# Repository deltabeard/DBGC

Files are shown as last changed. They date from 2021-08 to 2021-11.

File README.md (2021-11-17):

# DBGC: Deltabeard's Game Boy Cartridge
A reprogrammable Game Boy cartridge that utilises the Raspberry Pi RP2040.

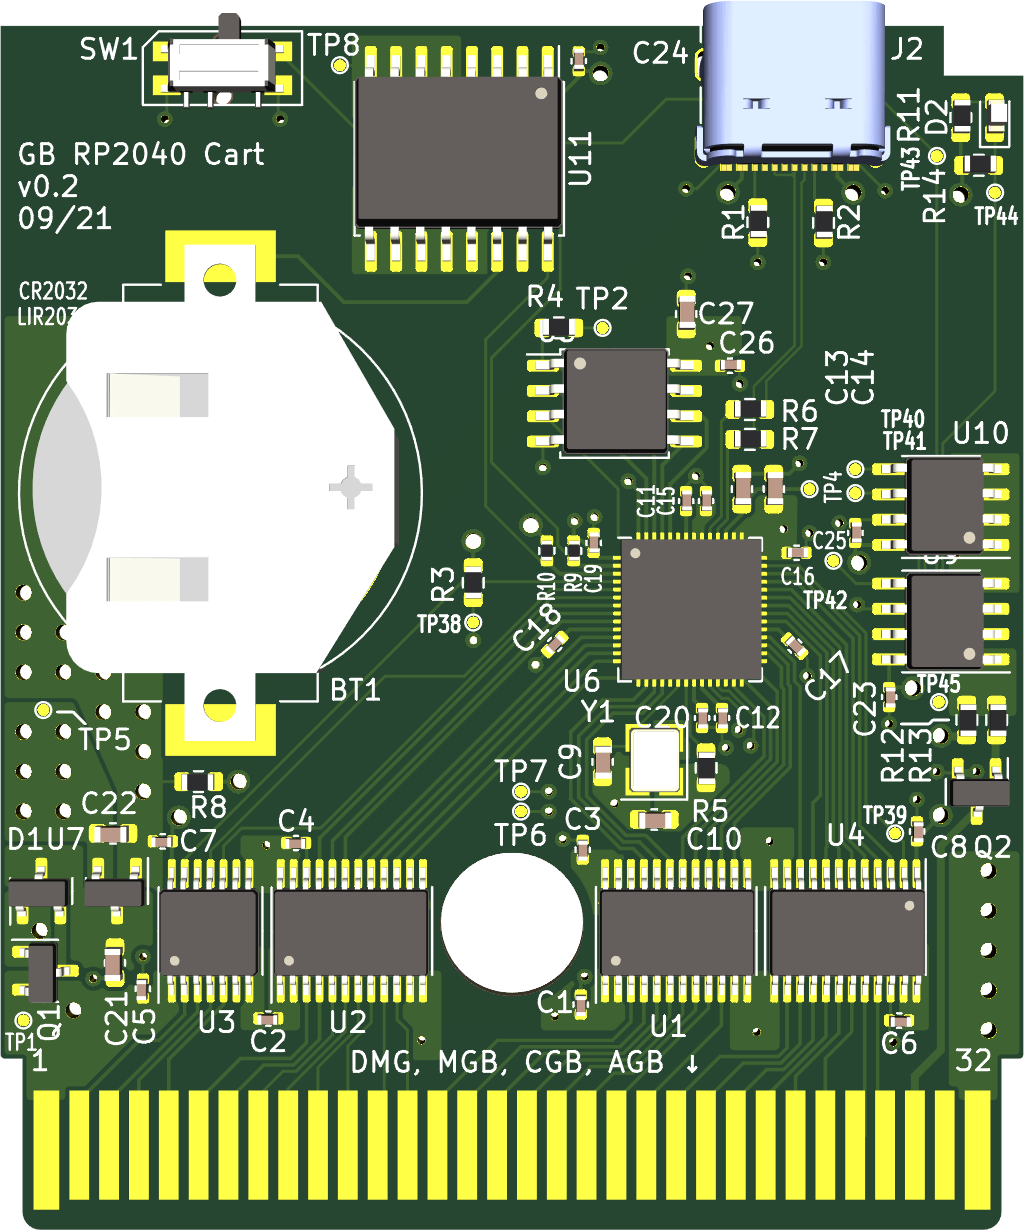
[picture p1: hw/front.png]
Front preview of PCB
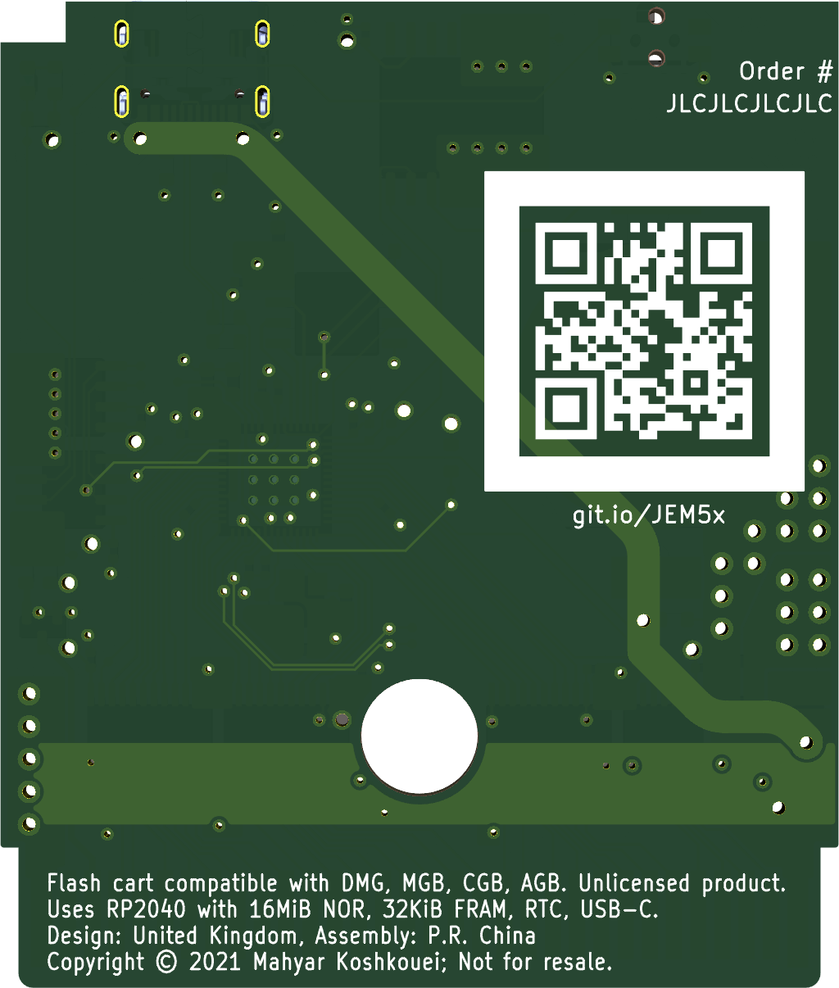
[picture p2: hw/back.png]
Back preview of PCB
 

## Supported Features
- Support for No MBC, MBC1 and MBC3 games (but only in single-speed mode).
- Real Time Clock (RTC) with battery backup.
- FRAM 32KiB for save support.
- NOR Flash 16MiB with support upto 8MiB ROM size.
- Can only play the one game programmed in at compile time.
- USB-C firmware upgrade support.

## Proposed Features

- Support multiple games on NOR Flash.
- USB-C flash storage explorer to store and retrieve save files and ROMs.
- USB-C networking support.

### Flash Storage
The flash storage will be partitioned to allow the user to either support large ROM sizes or increased number of ROMs stored. By setting the maximum ROM size to a smaller value, there will be more space to store other ROMs on the *Storage* partition. An example partition scheme is shown below.

| Partition | Size | Purpose |
|---|  --: |---|
| Firmware | 256KiB | Stores firmware for the RP2040 |
| Storage | Remainder | Wear-levelling filesystem holding ROMs and save files |

### USB-C Networking

By utilising RP2040 and TinyUSB features, the USB-C port can act as a networking device, which when attached to a host, will allow the RP2040 to connect to the Internet. Future features will allow supported Game Boy games to make connections to the internet.

## Notes
BOM is optimised for purchase from JLCPCB with SMT assembly. The cost of producing a single cart of this revision is approximately £15. This version of the PCB has major errors that can be seen in the [errata.md](https://github.com/deltabeard/DBGC/blob/master/errata.md) document. **Do not manufacture PCB version 0.3 or below**; instead wait for the next version or the one on the master branch. 

# License

The majority of the software within this project are licensed under the 
terms of the ISC License. Please see the header of each source file for 
license terms. In brief, the copyright and permission notices must not be
modified.

The PCB schematic and layout are licensed under the 
Creative Commons Attribution-ShareAlike 4.0 International (CC BY-SA 4.0) 
license. In brief, you may modify and share but only under the same license 
to allow others to continue modifying and sharing.

This project includes
[Libbet and the Magic Floor](https://github.com/pinobatch/libbet) and
[2048-gb](https://github.com/Sanqui/2048-gb), which are both 
licensed under the terms of the zlib license, and are included within this
project in an unmodified binary form for testing purposes.

# Showcase

- [Pokemon Polished Crystal](https://github.com/Rangi42/polishedcrystal). A 
  major fan-made upgrade to Pokemon Crystal. Uses MBC3 with battery backed 
  SRAM and Real Time Clock. The version tested had CGB double-speed disabled,
  which caused minor graphical glitches within the game. An effort is made to
  fix these graphical glitches at https://github.com/deltabeard/polishedcrystal.
  DBGC does not currently support double-speed, so using it to play
  Polished Crystal may not result in the intended experience.

Pokemon Polished Crystal

- Mega Man 1. This commercial game uses MBC1 ROM banking.

megaman1

- [2048-gb](https://github.com/Sanqui/2048-gb). Open source homebrew game. 
  Uses no ROM banking.



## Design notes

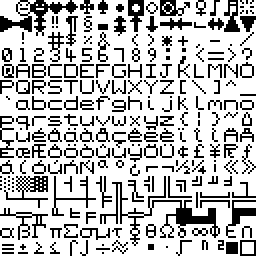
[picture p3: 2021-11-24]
sw/dmg/F77SMC6.png

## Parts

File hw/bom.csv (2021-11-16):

Comment | Designator | Footprint | LCSC
Battery_Cell | BT1 | Project_Specific:MY-2032-11 | C964835
100n | C1,C2,C3,C4,C5,C6,C7,C8,C10,C13,C14,C16,C17,C18,C19,C20,C21,C26,C27 | Capacitor_SMD:C_0402_1005Metric | C1525
30p | C11,C12 | Capacitor_SMD:C_0402_1005Metric | C1570
1u | C9,C15,C22,C23,C24 | Capacitor_SMD:C_0402_1005Metric | C52923
D_Dual_CommonCathode_AAK_Split | D1 | Package_TO_SOT_SMD:SOT-23 | C68978
LED | D2 | LED_SMD:LED_0603_1608Metric | C2286
SM4007PL | D3 | Diode_SMD:D_SOD-123F | C64898
GameBoy_Cartridge | J1 | Gekkio_Connector_PCBEdge:GameBoy_Cartridge_1x32_P1.50mm_Full
USB_C_Receptacle_USB2.0 | J2 | Connector_USB:USB_C_Receptacle_Palconn_UTC16-G | C167321
Debug | J3 | Connector_PinSocket_1.27mm:PinSocket_1x03_P1.27mm_Vertical
Motor_DC | M1 | Connector_PinHeader_1.27mm:PinHeader_1x02_P1.27mm_Vertical
SI2301CDS-T1-GE3 | Q1 | Package_TO_SOT_SMD:SOT-23 | C10487
N-Channel | Q2,Q3 | Package_TO_SOT_SMD:SOT-23 | C8545
25k | R1,R2,R3,R12 | Resistor_SMD:R_0402_1005Metric | C25900
100k | R10 | Resistor_SMD:R_0603_1608Metric | C25803
330R | R11,R13,R14 | Resistor_SMD:R_0603_1608Metric | C23138
5k1 | R4,R5 | Resistor_SMD:R_0402_1005Metric | C25905
1k | R6,R7 | Resistor_SMD:R_0603_1608Metric | C21190
27.4R | R8,R9 | Resistor_SMD:R_0603_1608Metric | C25190
SW_SPST | SW1 | Button_Switch_SMD:SW_SPST_TL3342 | C318886
TestPoint | TP1,TP2 | TestPoint:TestPoint_Pad_D1.0mm
TestPoint | TP3,TP5 | TestPoint:TestPoint_THTPad_D1.0mm_Drill0.5mm
SN74LVC8T245PW | U1,U2,U4 | Package_SO:TSSOP-24_4.4x7.8mm_P0.65mm | C27643
TXU0104 | U3 | Package_SO:TSSOP-14_4.4x5mm_P0.65mm
W25Q128JVSIQ | U5 | Package_SO:SOIC-8_5.23x5.23mm_P1.27mm | C97521
RP2040 | U6 | RP_RP2040:RP2040-QFN-56 | C2040
XC6206P332MR | U7 | Package_TO_SOT_SMD:SOT-23 | C5446
DS1302Z+ | U8 | Package_SO:SOIC-8_3.9x4.9mm_P1.27mm | C265479
MB85RS256B | U9 | Package_SO:SOIC-8_3.9x4.9mm_P1.27mm | C8742
Crystal_GND24 | Y1 | Crystal:Crystal_SMD_3225-4Pin_3.2x2.5mm | C9002
32.768kHz | Y2 | Crystal:Crystal_SMD_Abracon_ABS25-4Pin_8.0x3.8mm | C252402

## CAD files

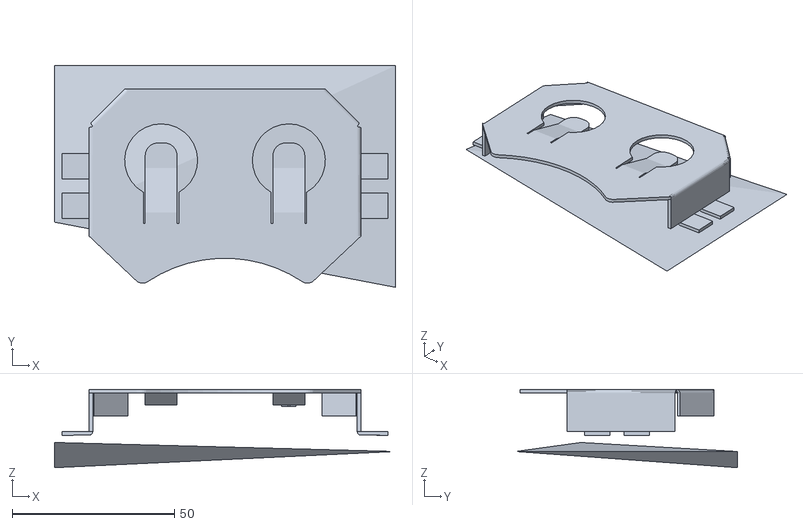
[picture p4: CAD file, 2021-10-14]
hw/models/OBJ_NEW_PCB.obj
105.1 x 68.3 x 24.2

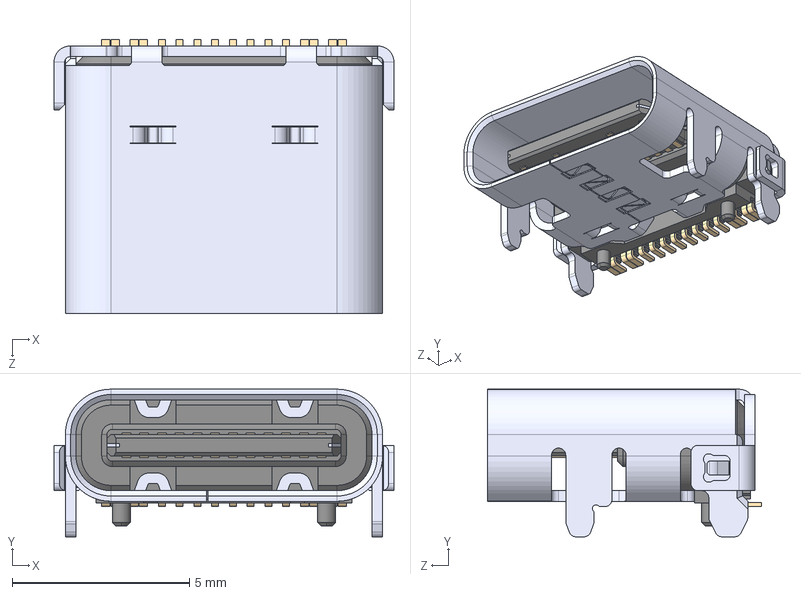
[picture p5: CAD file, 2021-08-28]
hw/models/USB4105-GF-A.step
9.58 x 4.16 x 7.71 mm

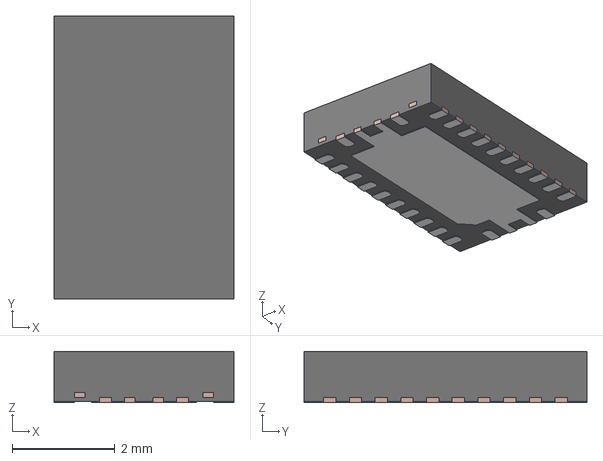
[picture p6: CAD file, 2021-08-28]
hw/models/CLXC8T245QRHLRQ1.stp
3.50 x 5.50 x 1.00 mm
FRAME
MOLD

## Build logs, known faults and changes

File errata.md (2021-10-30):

# Errata

Problems that cannot be solved via software updates.

## PCB dated "09/21"

### Major
- USB differential signals are connected the wrong way round.
  The fix is to cross the signals at the resistors using magnet wire (or alternative).
- The IO2 and IO3 connections to the NOR Flash are connected incorrectly. Possible fixes:
  - Use magnet wire to cross the IO2 and IO3 signals. v0.2 and above requires this fix.
  - Use single-IO or dual-IO flash access, which use IO0 or IO0 and IO1, respectively.
  
### Minor
- The CR2032 cell holder is too far in the PCB, making it difficult to remove the cell from the holder.
- The RTC IC is too close to the top edge of the PCB, making it difficult to place within a GB cartridge enclosure.
- The LED light does not work.

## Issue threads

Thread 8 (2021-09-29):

hw: the LED light does not work

deltabeard, 2021-09-29:

deltabeard, 2021-11-17:
Won't fix. The PCB fab did not populate the LED in the correct orientation.

Closed 2021-11-17.

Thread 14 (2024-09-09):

Add RP2350 support

deltabeard, 2024-09-09:
The RP2350 has improvements to the PIO that includes:

- Improved GPIO input/output delay and skew
- Reduced DMA request (DREQ) latency by one cycle vs RP2040
- Use of PSRAM

These features may allow for improvements in DBGC, and possibly allow for support for CGB clock speed games.

8bitZeta, 2024-12-03:
Are there any updates to this?

deltabeard, 2024-12-04:
No. I don't think changes of the RP2350 are enough to support double speed. With the larger internal RAM, it may be possible to play games at double speed, but the communication with the PSRAM and NOR Flash are still limited to their maximum frequency  of 133 MHz. So larger games that need to run off of external storage will be too slow for CGB double speed games.

Only other method is to use a parallel flash/RAM module and use the RP2040 or RP2530 as a MBC chip.

8bitZeta, 2024-12-07:
How feasible do you think the parallel approach would be?

I know the current metric is using an FPGA/CPLD to stand-in for the MBC, but I feel if it could be completely replicated via simple RPi chips, that would far easier to create and maintain.

deltabeard, 2024-12-14:
The issue is the time taken to obtain the date requested on the parallel bus by the Game Boy from the SPI NOR flash by the RP2040. The NOR Flash is typically limited to 133MHz, but maybe Hyperram, or something similar, could be used instead to obtain the ROM data with sufficient speed. This is because Hyperram is 200MHz and also uses double data rate (DDR). The RP2040 or RP2350 would have to use the PIO to communicate with the Hyperram, as the RP2040 and RP2350 does not support DDR in their QSPI peripheral. It may be possible to determine how much time it would take to receive a byte of data from the Hyperram using the PIO.

My suggestion earlier was to have a parallel flash chip connected directly to the parallel bus, which would remove the delay in the RP2040 getting the data from the SPI flash. But I haven't explored how that would exactly work. The MBC would be emulated by the RP2040, as processing data on the internal SRAM is very fast.

To that end, ROMs that are small enough to be stored entirely within the RP2040 SRAM should be able to run at double speed, but CGB games are typically much larger than the size of the RP2040 SRAM. Although, some CGB games use at least 512kB flash, they only use a small number of bank in their code.

deltabeard, 2024-12-14:
Since the DMG is ~4.2MHz, the cart has ~238nS to put the ROM data onto the bus. In double speed mode at ~8.4MHz, the cart has ~119nS to put the ROM data onto the bus.

A QSPI NOR Flash at 133MHz that can use Fast Read Quad I/O (EBh), would take 21 clock cycles to read the first byte of data from the flash given an address. This would take at least `(1/133e6)*21*1e9=` 158nS, which is okay for DMG but too slow for CGB double speed. This of course doesn't take into account the delay in the RP2040 reading the address from the cart bus, processing it for MBC commands, and any delays on the internal RP2040 CPU bus.

With the Hyperram, or an alternative Octa-SPI DDR chip, the time taken for the Hyperram to return the first byte of data when given a read instruction and the address is `(cmd_addr_clocks+cmd_full_latency)*data_rate*1e9=` 50nS, where `cmd_addr_clocks` is the number of clock transitions required for the command (6); `cmd_full_latency` is the number of clock transitions until the first data is issued by the Hyperram when the longest duration of latency is considered (14); and data_rate is half a period, since the Hyperram is DDR.
Since the Hyperram requires only at least 50nS, that leaves a good ~70nS to take into account other delays. An additional delay is the PIO peripheral.

It might be possible to support the CGB double speed mode with the RP2040 and RP2350. Although I do not think that the RP2350 introduces any much benefit over the RP2040 in this use case.

To save even more time, since the Hyperram is 8-bit bus, maybe the pins of the Hyperram could be connected to the Game Boy bus directly using a switch. So instead of the RP2040 reading this data and then putting it on the Game Boy bus, the Hyperram bus could be connected to the Game Boy bus directly, with a switch controlling when the Hyperram should be driving the bus.

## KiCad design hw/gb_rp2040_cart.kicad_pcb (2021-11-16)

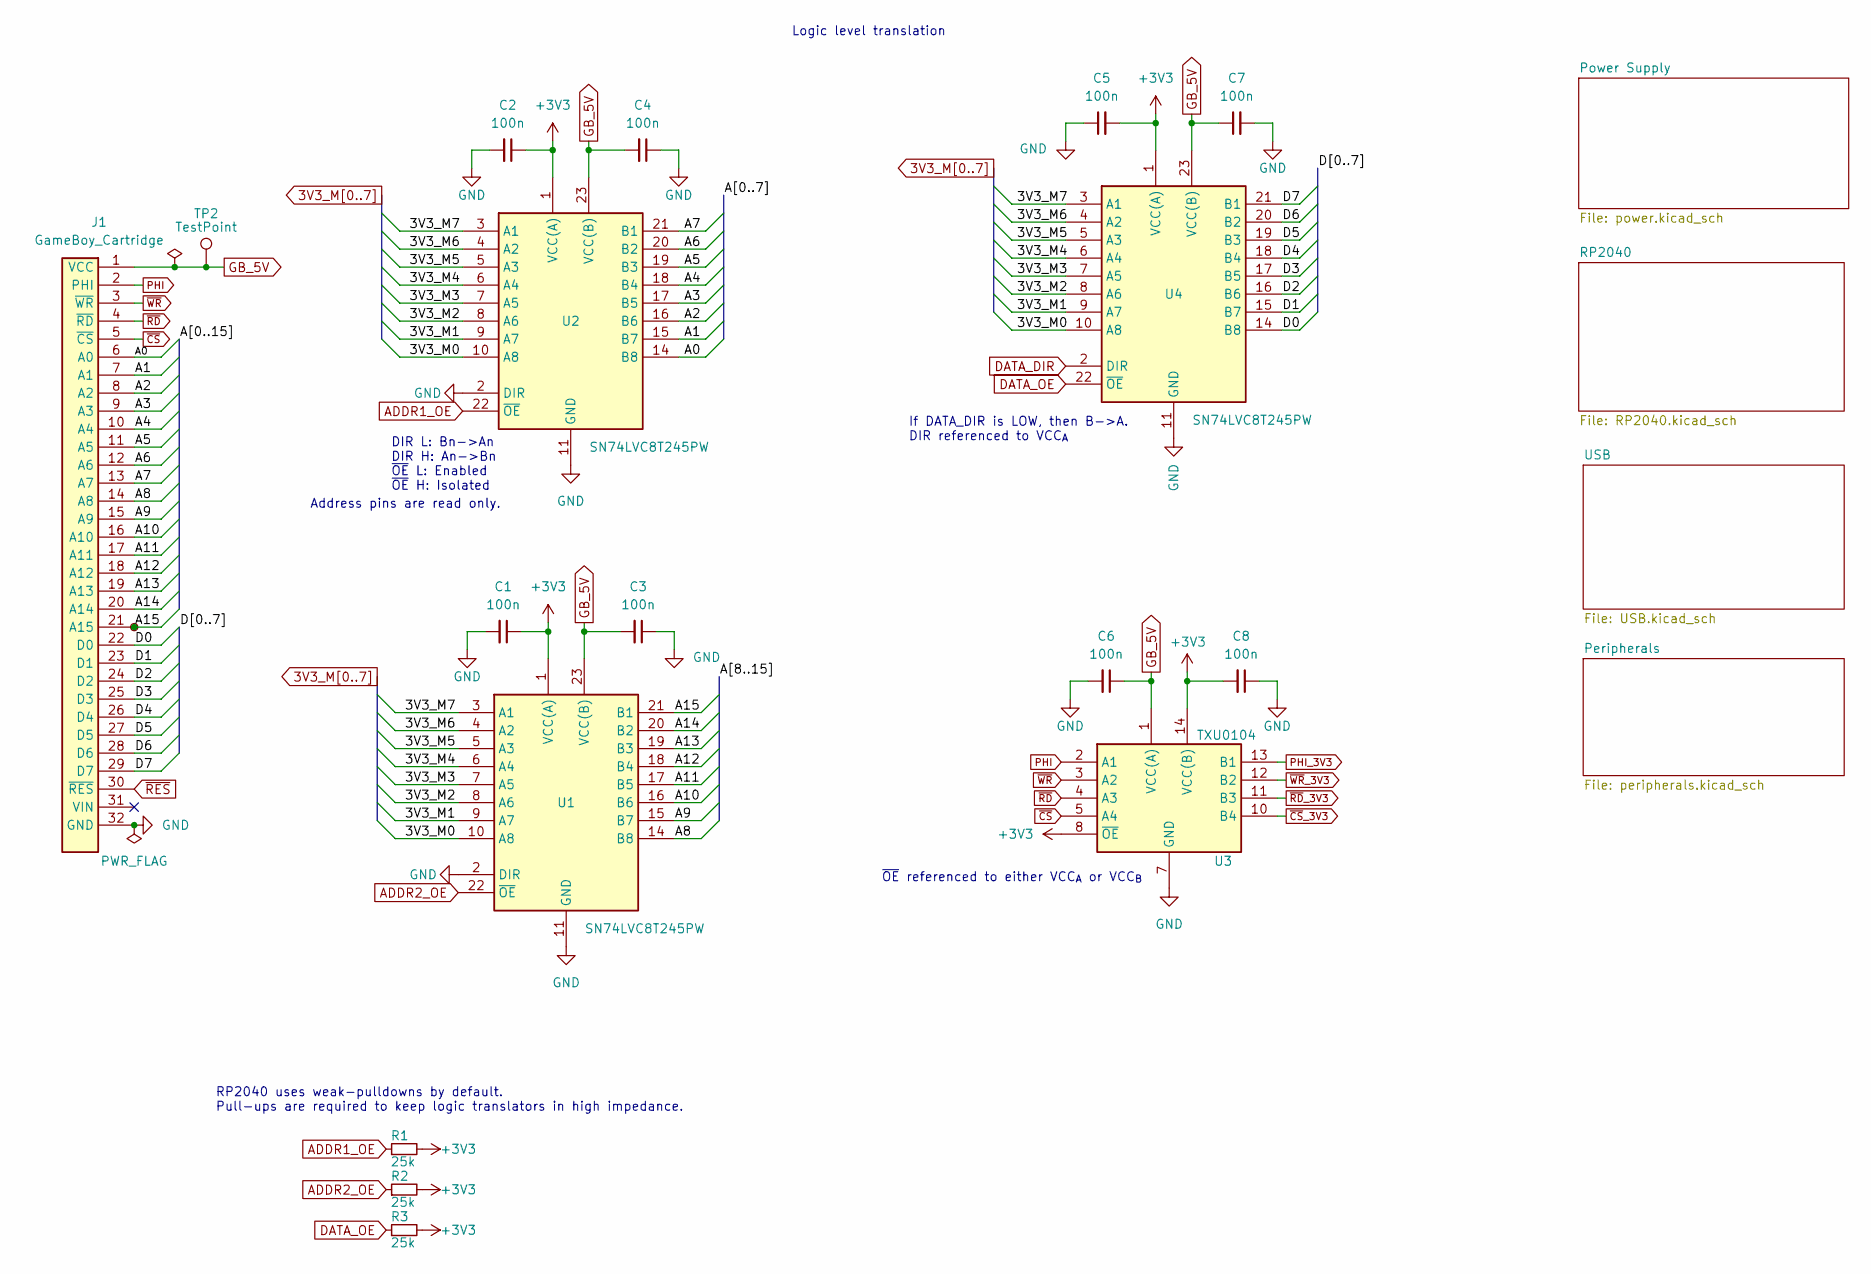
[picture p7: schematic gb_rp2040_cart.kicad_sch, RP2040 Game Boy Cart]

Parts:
C1, C2, C3, C4, C5, C6, C7, C8: 100n; C_0402_1005Metric; LCSC C1525
J1: GameBoy_Cartridge; GameBoy_Cartridge_1x32_P1.50mm_Full
R1, R2, R3: 25k; R_0402_1005Metric; LCSC C25900
TP1, TP2: TestPoint; TestPoint_Pad_D1.0mm
U1, U2, U4: SN74LVC8T245PW; TSSOP-24_4.4x7.8mm_P0.65mm; LCSC C27643
U3: TXU0104; TSSOP-14_4.4x5mm_P0.65mm

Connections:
3V3_M0: U1.10 (A8), U2.10 (A8), U4.10 (A8); also elsewhere on the board
3V3_M1: U1.9 (A7), U2.9 (A7), U4.9 (A7); also elsewhere on the board
3V3_M2: U1.8 (A6), U2.8 (A6), U4.8 (A6); also elsewhere on the board
3V3_M3: U1.7 (A5), U2.7 (A5), U4.7 (A5); also elsewhere on the board
3V3_M4: U1.6 (A4), U2.6 (A4), U4.6 (A4); also elsewhere on the board
3V3_M5: U1.5 (A3), U2.5 (A3), U4.5 (A3); also elsewhere on the board
3V3_M6: U1.4 (A2), U2.4 (A2), U4.4 (A2); also elsewhere on the board
3V3_M7: U1.3 (A1), U2.3 (A1), U4.3 (A1); also elsewhere on the board
+3V3: C1.1, C2.1, C5.2, C8.2, R1.2, R2.2, R3.2, U1.1 (VCC(A)), U2.1 (VCC(A)), U3.8 (~OE), U3.14 (VCC(B)), U4.1 (VCC(A)); also elsewhere on the board
/A0: J1.6 (A0), U2.14 (B8)
/A1: J1.7 (A1), U2.15 (B7)
/A2: J1.8 (A2), U2.16 (B6)
/A3: J1.9 (A3), U2.17 (B5)
/A4: J1.10 (A4), U2.18 (B4)
/A5: J1.11 (A5), U2.19 (B3)
/A6: J1.12 (A6), U2.20 (B2)
/A7: J1.13 (A7), U2.21 (B1)
/A8: J1.14 (A8), U1.14 (B8)
/A9: J1.15 (A9), U1.15 (B7)
/A10: J1.16 (A10), U1.16 (B6)
/A11: J1.17 (A11), U1.17 (B5)
/A12: J1.18 (A12), U1.18 (B4)
/A13: J1.19 (A13), U1.19 (B3)
/A14: J1.20 (A14), U1.20 (B2)
/A15: J1.21 (A15), TP1.1, U1.21 (B1)
/D0: J1.22 (D0), U4.14 (B8)
/D1: J1.23 (D1), U4.15 (B7)
/D2: J1.24 (D2), U4.16 (B6)
/D3: J1.25 (D3), U4.17 (B5)
/D4: J1.26 (D4), U4.18 (B4)
/D5: J1.27 (D5), U4.19 (B3)
/D6: J1.28 (D6), U4.20 (B2)
/D7: J1.29 (D7), U4.21 (B1)
ADDR1_OE: R1.1, U2.22 (~OE); also elsewhere on the board
ADDR2_OE: R2.1, U1.22 (~OE); also elsewhere on the board
DATA_DIR: U4.2 (DIR); also elsewhere on the board
DATA_OE: R3.1, U4.22 (~OE); also elsewhere on the board
GB_5V: C3.2, C4.2, C6.1, C7.1, J1.1 (VCC), TP2.1, U1.23 (VCC(B)), U1.24 (VCC(B)), U2.23 (VCC(B)), U2.24 (VCC(B)), U3.1 (VCC(A)), U4.23 (VCC(B)), U4.24 (VCC(B)); also elsewhere on the board
PHI: J1.2 (PHI), U3.2 (A1)
PHI_3V3: U3.13 (B1); also elsewhere on the board
~CS: J1.5 (~CS), U3.5 (A4)
~CS_3V3: U3.10 (B4); also elsewhere on the board
~RD: J1.4 (~RD), U3.4 (A3)
~RD_3V3: U3.11 (B3); also elsewhere on the board
~RES: J1.30 (~RES); also elsewhere on the board
~WR: J1.3 (~WR), U3.3 (A2)
~WR_3V3: U3.12 (B2); also elsewhere on the board

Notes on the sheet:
RP2040 uses weak-pulldowns by default. Pull-ups are required to keep logic translators in high impedance.
Address pins are read only.
DIR L: Bn->An DIR H: An->Bn ~{OE} L: Enabled ~{OE} H: Isolated
Logic level translation
~{OE} referenced to either VCC_{A} or VCC_{B}
If DATA_DIR is LOW, then B->A. DIR referenced to VCC_{A}

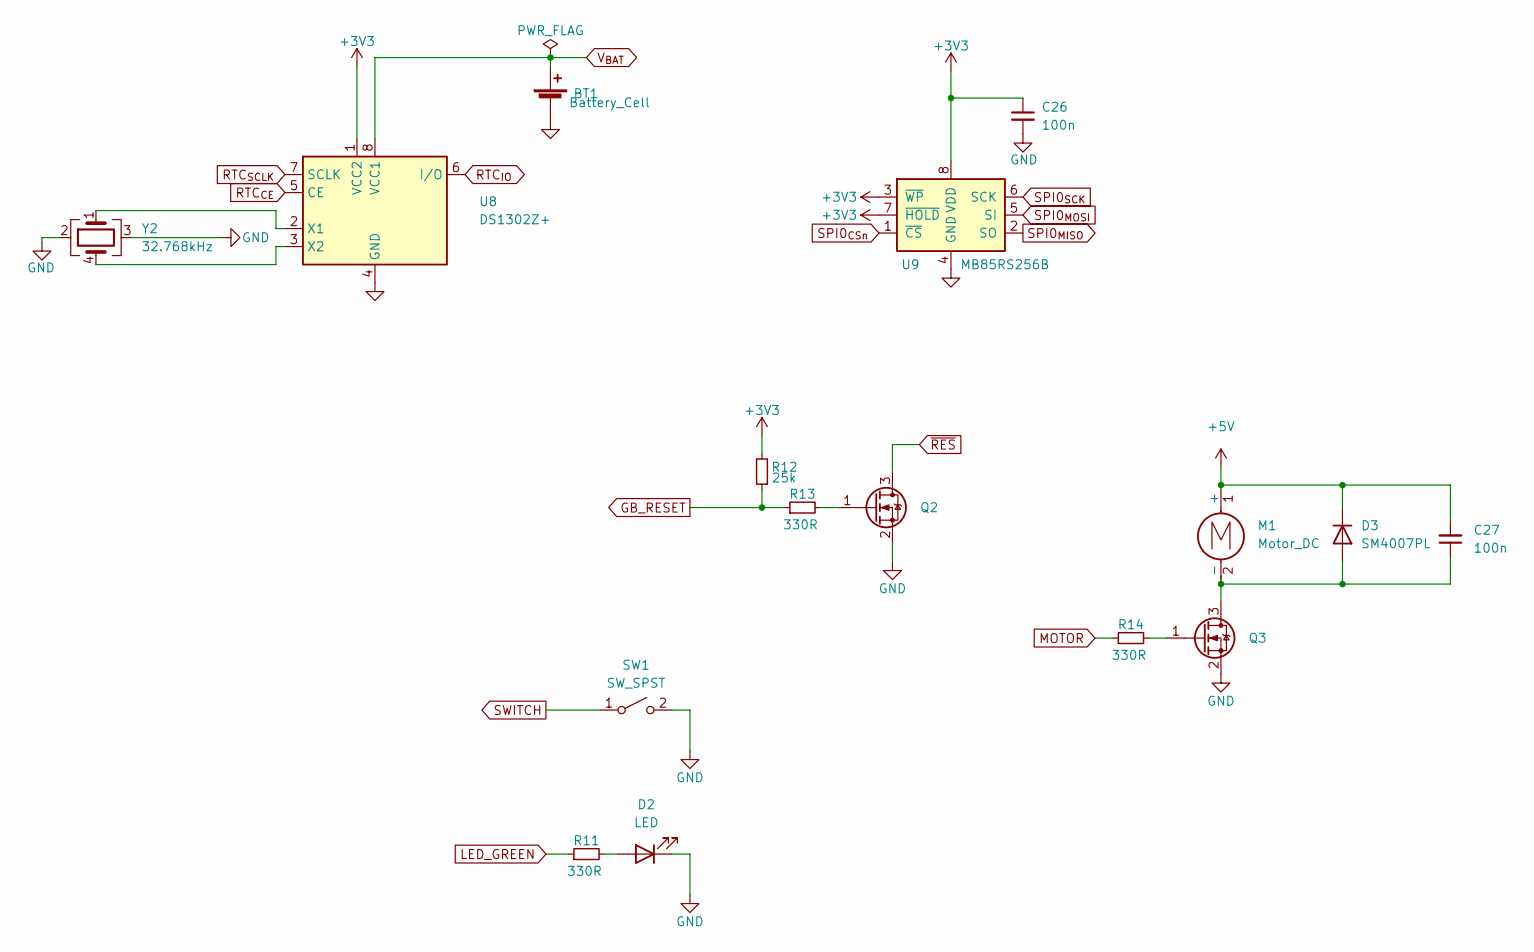
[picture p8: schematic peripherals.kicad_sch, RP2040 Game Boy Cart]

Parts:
BT1: Battery_Cell; MY-2032-11; LCSC C964835
C26, C27: 100n; C_0402_1005Metric; LCSC C1525
D2: LED; LED_0603_1608Metric; LCSC C2286
D3: SM4007PL; D_SOD-123F; LCSC C64898
M1: Motor_DC; PinHeader_1x02_P1.27mm_Vertical
Q2, Q3: N-Channel; SOT-23; LCSC C8545
R11, R13, R14: 330R; R_0603_1608Metric; LCSC C23138
R12: 25k; R_0402_1005Metric; LCSC C25900
SW1: SW_SPST; SW_SPST_TL3342; LCSC C318886
U8: DS1302Z+; SOIC-8_3.9x4.9mm_P1.27mm; LCSC C265479
U9: MB85RS256B; SOIC-8_3.9x4.9mm_P1.27mm; LCSC C8742
Y2: 32.768kHz; Crystal_SMD_Abracon_ABS25-4Pin_8.0x3.8mm; LCSC C252402

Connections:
+3V3: C26.1, R12.2, U8.1 (VCC2), U9.3 (~WP), U9.7 (~HOLD), U9.8 (VDD); also elsewhere on the board
+5V: C27.2, D3.1 (K), M1.1 (+); also elsewhere on the board
GB_RESET: R12.1, R13.1; also elsewhere on the board
LED_GREEN: R11.1; also elsewhere on the board
MOTOR: R14.1; also elsewhere on the board
unnamed: C27.1, D3.2 (A), M1.2 (-), Q3.3 (D)
unnamed: D2.2 (A), R11.2
unnamed: Q2.1 (G), R13.2
unnamed: Q3.1 (G), R14.2
unnamed: U8.2 (X1), Y2.1
unnamed: U8.3 (X2), Y2.4
RTC_{CE}: U8.5 (CE); also elsewhere on the board
RTC_{IO}: U8.6 (I/O); also elsewhere on the board
RTC_{SCLK}: U8.7 (SCLK); also elsewhere on the board
SPI0_{CSn}: U9.1 (~CS); also elsewhere on the board
SPI0_{MISO}: U9.2 (SO); also elsewhere on the board
SPI0_{MOSI}: U9.5 (SI); also elsewhere on the board
SPI0_{SCK}: U9.6 (SCK); also elsewhere on the board
SWITCH: SW1.1 (A); also elsewhere on the board
V_{BAT}: BT1.1 (+), U8.8 (VCC1)
~RES: Q2.3 (D); also elsewhere on the board

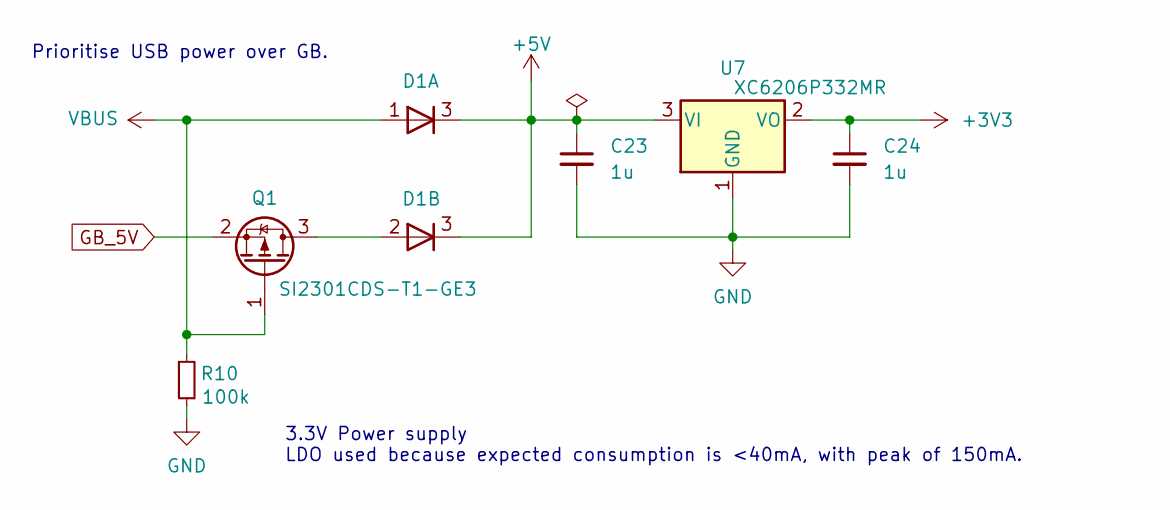
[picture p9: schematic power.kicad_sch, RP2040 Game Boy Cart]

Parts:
C23, C24: 1u; C_0402_1005Metric; LCSC C52923
D1: D_Dual_CommonCathode_AAK_Split; SOT-23; LCSC C68978
Q1: SI2301CDS-T1-GE3; SOT-23; LCSC C10487
R10: 100k; R_0603_1608Metric; LCSC C25803
U7: XC6206P332MR; SOT-23; LCSC C5446

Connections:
+3V3: C24.1, U7.2 (VO); also elsewhere on the board
+5V: C23.1, D1.3 (K), U7.3 (VI); also elsewhere on the board
GB_5V: Q1.2 (S); also elsewhere on the board
unnamed: D1.2 (K), Q1.3 (D)
VBUS: D1.1 (A), Q1.1 (G), R10.1; also elsewhere on the board

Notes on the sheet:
Prioritise USB power over GB.
3.3V Power supply LDO used because expected consumption is <40mA, with peak of 150mA.

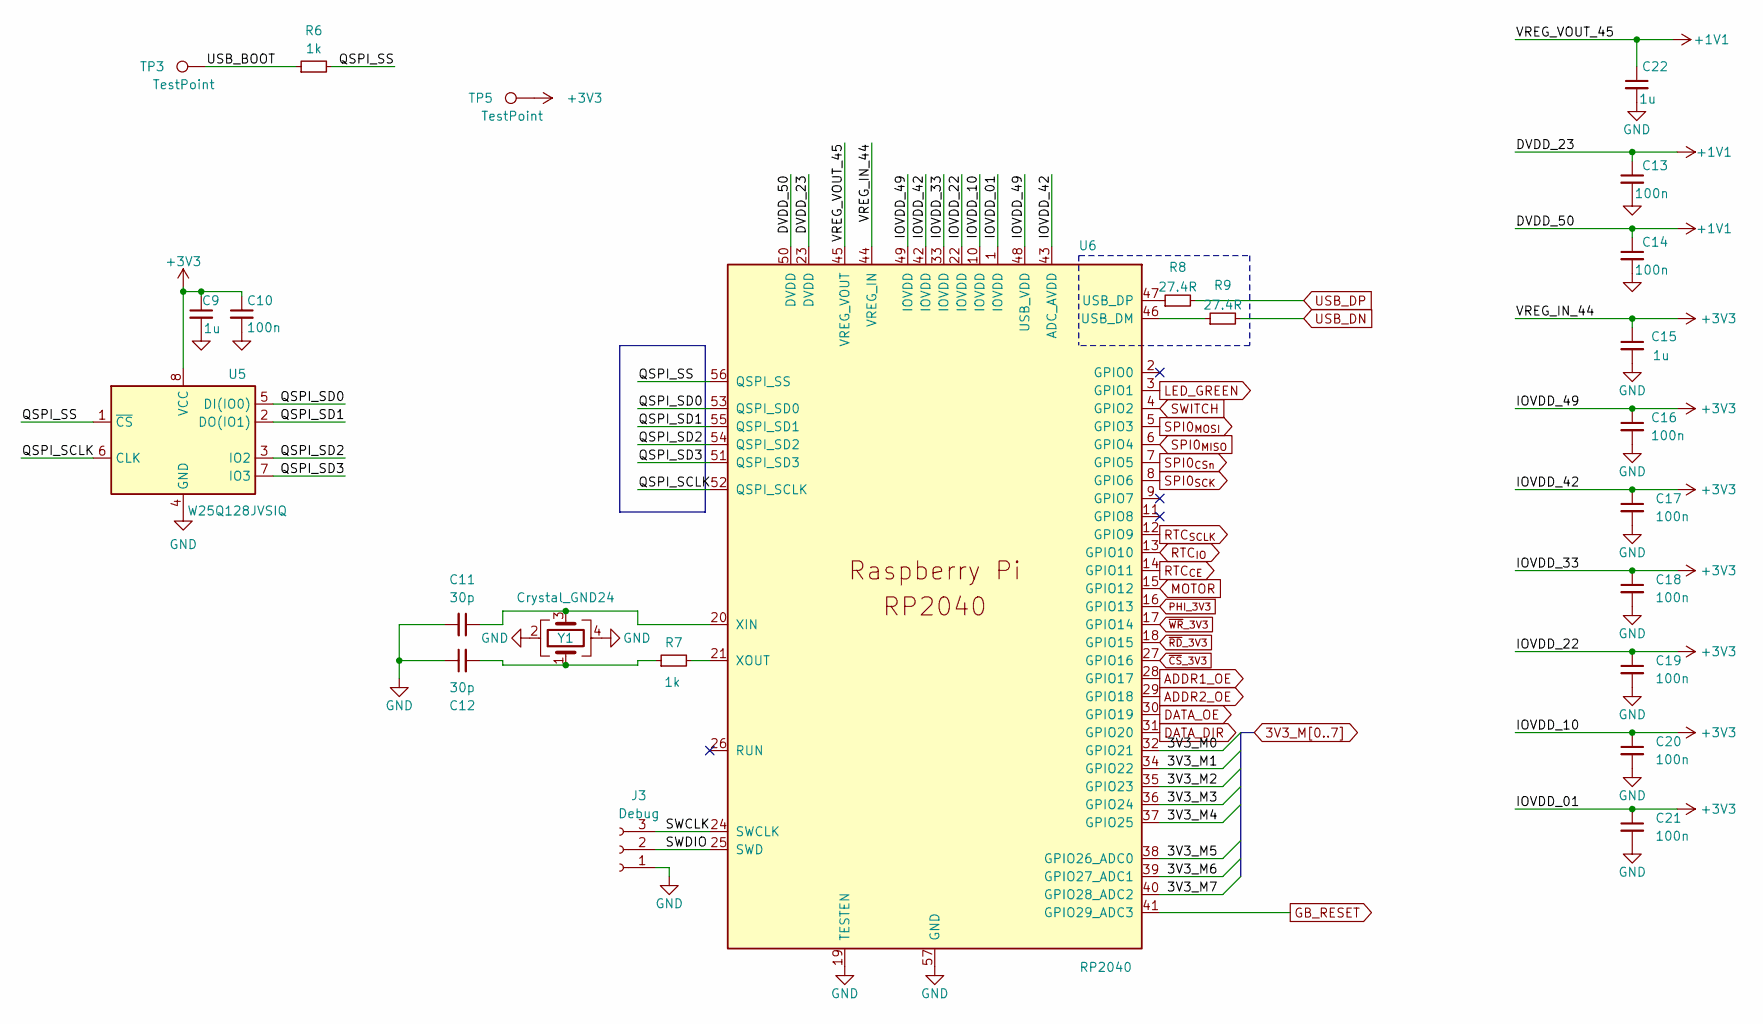
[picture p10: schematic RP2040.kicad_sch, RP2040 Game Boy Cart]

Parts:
C9, C15, C22: 1u; C_0402_1005Metric; LCSC C52923
C10, C13, C14, C16, C17, C18, C19, C20, C21: 100n; C_0402_1005Metric; LCSC C1525
C11, C12: 30p; C_0402_1005Metric; LCSC C1570
J3: Debug; PinSocket_1x03_P1.27mm_Vertical
R6, R7: 1k; R_0603_1608Metric; LCSC C21190
R8, R9: 27.4R; R_0603_1608Metric; LCSC C25190
TP3, TP5: TestPoint; TestPoint_THTPad_D1.0mm_Drill0.5mm
U5: W25Q128JVSIQ; SOIC-8_5.23x5.23mm_P1.27mm; LCSC C97521
U6: RP2040; RP2040-QFN-56; LCSC C2040
Y1: Crystal_GND24; Crystal_SMD_3225-4Pin_3.2x2.5mm; LCSC C9002

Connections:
3V3_M0: U6.32 (GPIO21); also elsewhere on the board
3V3_M1: U6.34 (GPIO22); also elsewhere on the board
3V3_M2: U6.35 (GPIO23); also elsewhere on the board
3V3_M3: U6.36 (GPIO24); also elsewhere on the board
3V3_M4: U6.37 (GPIO25); also elsewhere on the board
3V3_M5: U6.38 (GPIO26_ADC0); also elsewhere on the board
3V3_M6: U6.39 (GPIO27_ADC1); also elsewhere on the board
3V3_M7: U6.40 (GPIO28_ADC2); also elsewhere on the board
+1V1: C13.1, C14.1, C22.1, U6.23 (DVDD), U6.45 (VREG_VOUT), U6.50 (DVDD)
+3V3: C9.1, C10.1, C15.1, C16.1, C17.1, C18.1, C19.1, C20.1, C21.1, TP5.1, U5.8 (VCC), U6.1 (IOVDD), U6.10 (IOVDD), U6.22 (IOVDD), U6.33 (IOVDD), U6.42 (IOVDD), U6.43 (ADC_AVDD), U6.44 (VREG_IN), U6.48 (USB_VDD), U6.49 (IOVDD); also elsewhere on the board
/RP2040/QSPI_SCLK: U5.6 (CLK), U6.52 (QSPI_SCLK)
/RP2040/QSPI_SD0: U5.5 (DI(IO0)), U6.53 (QSPI_SD0)
/RP2040/QSPI_SD1: U5.2 (DO(IO1)), U6.55 (QSPI_SD1)
/RP2040/QSPI_SD2: U5.3 (IO2), U6.54 (QSPI_SD2)
/RP2040/QSPI_SD3: U5.7 (IO3), U6.51 (QSPI_SD3)
/RP2040/QSPI_SS: R6.2, U5.1 (~CS), U6.56 (QSPI_SS)
/RP2040/SWCLK: J3.3, U6.24 (SWCLK)
/RP2040/SWDIO: J3.2, U6.25 (SWD)
/RP2040/USB_BOOT: R6.1, TP3.1
ADDR1_OE: U6.28 (GPIO17); also elsewhere on the board
ADDR2_OE: U6.29 (GPIO18); also elsewhere on the board
DATA_DIR: U6.31 (GPIO20); also elsewhere on the board
DATA_OE: U6.30 (GPIO19); also elsewhere on the board
GB_RESET: U6.41 (GPIO29_ADC3); also elsewhere on the board
LED_GREEN: U6.3 (GPIO1); also elsewhere on the board
MOTOR: U6.15 (GPIO12); also elsewhere on the board
unnamed: C11.1, U6.20 (XIN), Y1.3
unnamed: C12.2, R7.1, Y1.1
unnamed: R7.2, U6.21 (XOUT)
unnamed: R8.1, U6.47 (USB_DP)
unnamed: R9.1, U6.46 (USB_DM)
PHI_3V3: U6.16 (GPIO13); also elsewhere on the board
RTC_{CE}: U6.14 (GPIO11); also elsewhere on the board
RTC_{IO}: U6.13 (GPIO10); also elsewhere on the board
RTC_{SCLK}: U6.12 (GPIO9); also elsewhere on the board
SPI0_{CSn}: U6.7 (GPIO5); also elsewhere on the board
SPI0_{MISO}: U6.6 (GPIO4); also elsewhere on the board
SPI0_{MOSI}: U6.5 (GPIO3); also elsewhere on the board
SPI0_{SCK}: U6.8 (GPIO6); also elsewhere on the board
SWITCH: U6.4 (GPIO2); also elsewhere on the board
USB_DN: R9.2; also elsewhere on the board
USB_DP: R8.2; also elsewhere on the board
~CS_3V3: U6.27 (GPIO16); also elsewhere on the board
~RD_3V3: U6.18 (GPIO15); also elsewhere on the board
~WR_3V3: U6.17 (GPIO14); also elsewhere on the board

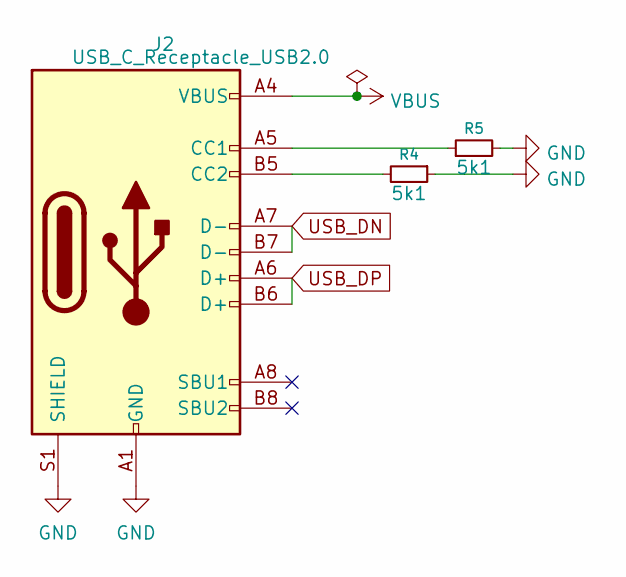
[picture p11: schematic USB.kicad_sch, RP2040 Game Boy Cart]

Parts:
J2: USB_C_Receptacle_USB2.0; USB_C_Receptacle_Palconn_UTC16-G; LCSC C167321
R4, R5: 5k1; R_0402_1005Metric; LCSC C25905

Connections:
unnamed: J2.A5 (CC1), R5.1
unnamed: J2.B5 (CC2), R4.2
USB_DN: J2.A7 (D-), J2.B7 (D-); also elsewhere on the board
USB_DP: J2.A6 (D+), J2.B6 (D+); also elsewhere on the board
VBUS: J2.A4 (VBUS), J2.A9 (VBUS), J2.B4 (VBUS), J2.B9 (VBUS); also elsewhere on the board

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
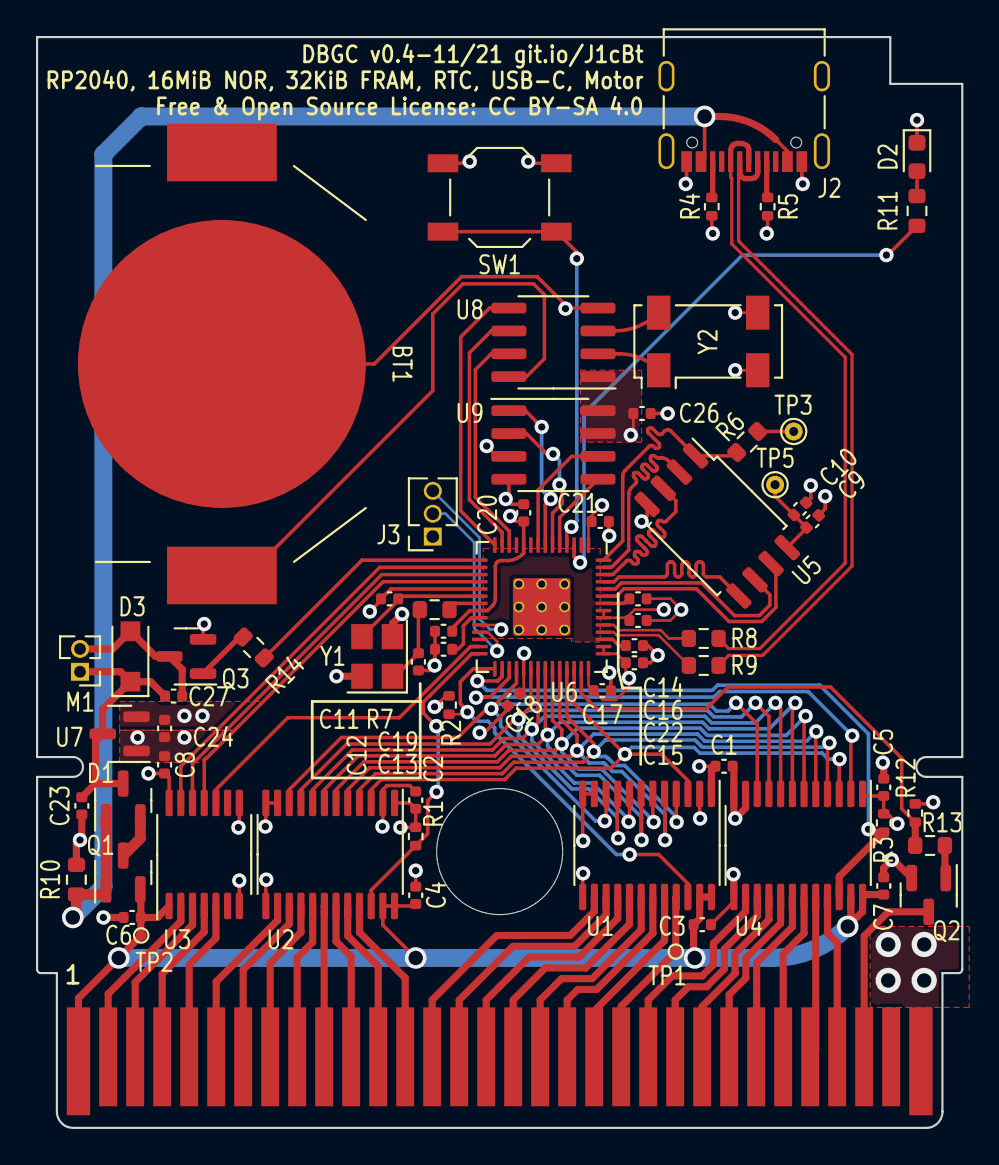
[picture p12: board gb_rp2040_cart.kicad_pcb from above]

Board: 4 copper layers, 51.4 x 60.6 mm, 67 parts (0 on the bottom side), 88 nets.

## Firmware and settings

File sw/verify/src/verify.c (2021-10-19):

#include <sys/cdefs.h>

#define _GNU_SOURCE

#include <stdio.h>
#include <string.h>
#include <stdlib.h>
#include <pico/stdlib.h>
#include <pico/bootrom.h>
#include <pico/binary_info.h>
#include <hardware/i2c.h>
#include <hardware/clocks.h>
#include <hardware/rtc.h>
#include <hardware/sync.h>
#include <pico/util/datetime.h>
#include <hardware/structs/xip_ctrl.h>
#include <verify.h>

#define OPT_LIKELY(expr)	__builtin_expect(!!(expr), 1)
#define OPT_UNLIKELY(expr)	__builtin_expect(!!(expr), 0)
#define OPT_INLINE		inline
#define OPT_FORCE_INLINE	__attribute__((__always_inline__)) OPT_INLINE

#define ARRAYSIZE(array)	(sizeof(array)/sizeof(array[0]))
#define CLR_SCRN		"\033[2J"

#define I2C_PCA9536_ADDR 0b01000001
#define I2C_DS3231M_ADDR 0b01101000

#define CURRENT_MILLENNIUM	21
#define RTC_YEARS_EPOCH		((CURRENT_MILLENNIUM - 1) * 100)

struct func_map {
	char *long_arg;
	char *help;
	void (*func)(const char *cmd);
};

void func_help(const char *cmd);
void func_i2cscan(const char *cmd);
void func_i2csend(const char *cmd);
void func_i2crecv(const char *cmd);
void func_rtctemp(const char *cmd);
void func_rtcread(const char *cmd);
void func_rtcwrite(const char *cmd);
void func_gb(const char *cmd);
void func_set_clock(const char *cmd);

void func_play(const char *cmd);
void func_date(const char *cmd);
void func_reboot(const char *cmd);

static const struct func_map map[] = {
	{ "HELP",	"Print usage information",		func_help	},
	{ "I2C SCAN",	"Perform I2C bus scan",			func_i2cscan	},
	{ "I2C SEND",	"Send bytes 0xDD to address 0xAA on I2C bus\n"
			     "\t'I2C SEND 0xAA 0xDD [0xDD ...]'", func_i2csend	},
	{ "I2C RECV",	"Receive a byte from address 0xAA on I2C bus\n"
			     "\t'I2C RECV 0xAA'",		func_i2crecv	},
	{ "RTC TEMP",	"Read temperature from RTC",		func_rtctemp	},
	{ "RTC READ",	"Read date and time from RTC and set internal RTC",
								func_rtcread	},
	{ "RTC WRITE",	"Write date and time to internal RTC and set external RTC \n"
			"\t'RTC WRITE <DOTW>:<DAY>/<MONTH>/<YEAR> <HOUR>:<MIN>:<SEC>'",
			      					func_rtcwrite	},
	{ "GB",		"Turn GB on (0) or off (1)\n"
			       "\t'GB 1'",			func_gb		},
	{ "DATE",	"Read date and time from internal RTC",	func_date	},
	{ "PLAY",	"Play a game",			func_play	},
	{ "CLOCK",	"Set CPU clock speed",		func_set_clock	},
	{ "REBOOT",	"Reboot to USBBOOT",		func_reboot 	}
};

typedef enum {
	RTC_SEC = 0,
	RTC_MIN,
	RTC_HOUR,
	RTC_DAY,
	RTC_DATE,
	RTC_MONTH,
	RTC_YEAR,
	RTC_ALARM1_SEC,
	RTC_ALARM1_MIN,
	RTC_ALARM1_HOUR,
	RTC_ALARM1_DAY,
	RTC_ALARM1_DATE,
	RTC_ALARM2_MIN,
	RTC_ALARM2_HOUR,
	RTC_ALARM2_DAY,
	RTC_ALARM2_DATE,
	RTC_CONTROL,
	RTC_CONTROL_STATUS,
	RTC_CONTROL_AGING,
	RTC_CONTROL_TEMP_MSB = 0x11,
	RTC_CONTROL_TEMP_LSB = 0x12
} rtc_reg;

typedef enum {
	IO_EXP_INPUT_PORT = 0,
	IO_EXP_OUTPUT_PORT,
	IO_EXP_INVERSION,
	IO_EXP_DIRECTION
} io_exp_reg;

#include <hardware/pio.h>
#include "comms.pio.h"

#define ROM_BANK_SIZE   0x4000
#define CRAM_BANK_SIZE  0x2000
#define CART_RAM_ADDR   0xA000

#include <pokered.gbc.h>
#include <gb240p.gb.h>
#include <libbet.gb.h>
#include <hardware/vreg.h>
#include <pico/multicore.h>
#include <ctype.h>
#include <hardware/dma.h>
#include <hardware/structs/ssi.h>

typedef enum {
	MULTICORE_CMD_SM_ENABLED = 0,

	MULTICORE_CMD_MBC_ACCEPTED,
	MULTICORE_CMD_MBC_FAIL,

	MULTICORE_CMD_ROM_ACCEPTED,
	MULTICORE_CMD_ROM_FAIL,

	MULTICORE_CMD_RAM_ACCEPTED,
	MULTICORE_CMD_RAM_FAIL,

	MULTICORE_CMD_PLAYING
} multicore_cmd_e;

const uint16_t mbc_location = 0x0147;
const uint16_t bank_count_location = 0x0148;
const uint16_t ram_size_location = 0x0149;

const uint8_t cart_mbc_lut[0xFF] =
	{
	/* ROM Only */
	[0x00] = 0,

	/* MBC1 */
	[0x01] = 1, 1, 1,
	[0x04] = -1,

	/* MBC2 */
	[0x05] = 2, 2,
	[0x07] = -1,

	/* ROM with RAM (Unsupported) */
	[0x08] = -1, -1,
	[0x0A] = -1,

	/* MMM01 (Unsupported) */
	[0x0B] = -1, -1, -1,
	[0x0E] = -1,

	/* MBC3 */
	[0x0F] = 3, 3, 3, 3, 3,

	/* Everything else is unsupported for now. */
	[0x14] = -1
	};
const uint8_t cart_ram_lut[] =
	{
		0, 0, 1, 1, 0, 0, 0, 0, 1, 1, 0, 0, 0, 0, 0, 0,
		1, 0, 1, 1, 0, 0, 0, 0, 0, 0, 1, 1, 0, 0, 0, 0
	};
const uint16_t num_rom_banks_lut[] =
	{
		2, 4, 8, 16, 32, 64, 128, 256, 512
	};
const uint8_t num_ram_banks_lut[] = {0, 1, 1, 4, 16, 8};

void power_gb(bool turn_gb_on)
{
	uint8_t tx[2];
	tx[0] = IO_EXP_OUTPUT_PORT;
	tx[1] = 0b11111110 | !turn_gb_on;
	i2c_write_blocking(i2c_default, I2C_PCA9536_ADDR, tx,
			   sizeof(tx), false);
}

static inline bool pio_sm_is_rx_fifo_empty_mask(PIO pio, uint sm_mask) {
	check_pio_param(pio);
	return (pio->fstat & (sm_mask << PIO_FSTAT_RXEMPTY_LSB)) != 0;
}

void __no_inline_not_in_flash_func(core1_pio_manager)(void){
	unsigned sm_a15, sm_ncs, sm_do;
	const unsigned char *rom;
	unsigned char *ram = NULL;
	unsigned rom_sz, ram_sz;

	/* Cartridge information:
	 * Memory Bank Controller (MBC) type. */
	uint8_t mbc;
	/* Whether the MBC has internal RAM. */
	uint8_t cart_ram;
	/* Number of ROM banks in cartridge. */
	uint16_t num_rom_banks_mask;
	/* Number of RAM banks in cartridge. */
	uint8_t num_ram_banks;
	uint16_t selected_rom_bank = 1;
	uint8_t cart_ram_bank = 0;
	uint8_t enable_cart_ram = 0;
	/* Cartridge ROM/RAM mode select. */
	uint8_t cart_mode_select = 0;
	union
	{
		struct __attribute__ ((__packed__))
		{
			uint8_t sec;
			uint8_t min;
			uint8_t hour;
			uint8_t yday;
			uint8_t high;
		} rtc_bits;
		uint8_t cart_rtc[5];
	} rtc = { .cart_rtc = 0 };

	/* This will panic if sm is not available. */
	sm_a15 = pio_claim_unused_sm(pio0, true);
	sm_ncs = pio_claim_unused_sm(pio0, true);
	sm_do = pio_claim_unused_sm(pio0, true);
	gb_bus_program_init(pio0, sm_a15, sm_ncs, sm_do);

	/* Initialise Game Boy data communication. */
	power_gb(false);

	switch(multicore_fifo_pop_blocking())
	{
		default:
	case 1:
		rom = libbet_gb + (XIP_NOCACHE_NOALLOC_BASE - XIP_BASE);
		rom_sz = libbet_gb_len;
		break;

	case 2:
		rom = gb240p_gb + (XIP_NOCACHE_NOALLOC_BASE - XIP_BASE);
		rom_sz = gb240p_gb_len;
		break;

#if 1
	case 3:
		rom = pokered_gbc + (XIP_NOCACHE_NOALLOC_BASE - XIP_BASE);
		rom_sz = pokered_gbc_len;
		break;
#endif
	}

	/* Initialise ROM data. */
	/* Check if cartridge type is supported, and set MBC type. */
	{
		const uint8_t mbc_value = rom[mbc_location];
		const uint8_t ram_sz_value = rom[ram_size_location];

		if(mbc_value > sizeof(cart_mbc_lut) - 1 ||
			(mbc = cart_mbc_lut[mbc_value]) == 255u || mbc > 1)
		{
			multicore_fifo_push_blocking(MULTICORE_CMD_MBC_FAIL);
			return;
		}
		multicore_fifo_push_blocking(MULTICORE_CMD_MBC_ACCEPTED);

		num_ram_banks = num_ram_banks_lut[ram_sz_value];
		multicore_fifo_push_blocking(MULTICORE_CMD_RAM_ACCEPTED);

		cart_ram = cart_ram_lut[mbc_value];
		ram_sz = num_ram_banks * CRAM_BANK_SIZE;

		if(ram_sz != 0)
		{
			ram = calloc(ram_sz, sizeof(*ram));
			if(ram == NULL)
			{
				multicore_fifo_push_blocking(
					MULTICORE_CMD_RAM_FAIL);
				return;
			}
		}

		num_rom_banks_mask = num_rom_banks_lut[rom[bank_count_location]] - 1;
		multicore_fifo_push_blocking(MULTICORE_CMD_ROM_ACCEPTED);
	}

	/* Enable state machines. */
	pio_sm_set_enabled(pio0, sm_a15, true);
	pio_sm_set_enabled(pio0, sm_ncs, true);
	pio_sm_set_enabled(pio0, sm_do,  true);
	multicore_fifo_push_blocking(MULTICORE_CMD_SM_ENABLED);

	multicore_fifo_push_blocking(MULTICORE_CMD_PLAYING);

	/* Power cycle GB. */
	sleep_ms(100);
	power_gb(true);

	while(1)
	{
		/* Only read the address, which is stored in the most
		 * significant two bytes of the RX FIFO. */
		io_ro_32 *rx_sm_a15 = &pio0->rxf[sm_a15];
		io_ro_32 *rx_sm_ncs = &pio0->rxf[sm_ncs];
		io_wo_8 *tx_sm_do = (io_wo_8 *) &pio0->txf[sm_do];
		union {
			struct {
				uint16_t address;
				uint8_t data;
				uint8_t is_write;
			};
			uint32_t raw;
		} in;
		uint16_t address;
		uint8_t data;

		while(1)
		{
			if(pio_sm_is_rx_fifo_empty(pio0, sm_a15) == false)
			{
				in.raw = *rx_sm_a15;
				break;
			}
			else if(pio_sm_is_rx_fifo_empty(pio0, sm_ncs) == false)
			{
				in.raw = *rx_sm_ncs;

				/* Catch invalid addresses here. */
				if(in.address < 0xA000 || in.address > 0xBFFF)
					continue;

				break;
			}
		}

		address = in.address;

		if(in.is_write)
		{
			/* If we need to write data to ROM, then we obtain the
			 * data byte from the third byte of the RX FIFO. */
			data = in.data;

			multicore_fifo_push_blocking(in.raw);

			switch(address >> 12)
			{
			case 0x0:
			case 0x1:
				if(mbc > 0 && cart_ram)
					enable_cart_ram = ((data & 0x0F) == 0x0A);

				break;

			case 0x2:
			case 0x3:
				if(mbc == 1)
				{
					selected_rom_bank = (data & 0x1F) | (selected_rom_bank & 0x60);

					if((selected_rom_bank & 0x1F) == 0x00)
						selected_rom_bank++;
				}
				else if(mbc == 3)
				{
					selected_rom_bank = data & 0x7F;

					if(!selected_rom_bank)
						selected_rom_bank++;
				}

				selected_rom_bank = selected_rom_bank & num_rom_banks_mask;

				break;

			case 0x4:
			case 0x5:
				if(mbc == 1)
				{
					cart_ram_bank = (data & 3);
					selected_rom_bank = ((data & 3) << 5) | (selected_rom_bank & 0x1F);
					selected_rom_bank = selected_rom_bank & num_rom_banks_mask;
				}
				else if(mbc == 3)
					cart_ram_bank = data;

				break;

			case 0x6:
			case 0x7:
				cart_mode_select = (data & 1);
				break;

			case 0xA:
			case 0xB:
				if(cart_ram && enable_cart_ram)
				{
					if(mbc == 3 && cart_ram_bank >= 0x08)
						rtc.cart_rtc[cart_ram_bank -
						0x08] = data;
					else if(cart_mode_select &&
						cart_ram_bank < num_ram_banks)
					{
						ram[address - CART_RAM_ADDR + (cart_ram_bank * CRAM_BANK_SIZE)] = data;
					}
					else if(num_ram_banks)
					{
						ram[address -
						    CART_RAM_ADDR] = data;
					}
				}

				break;

			default:
				/* This is an invalid address. */
				break;
			}

			continue;
		}

		switch(address >> 12)
		{
		case 0x0:
		case 0x1:
		case 0x2:
		case 0x3:
			data = rom[address];
			break;

		case 0x4:
		case 0x5:
		case 0x6:
		case 0x7:
			if(mbc == 1 && cart_mode_select)
				data = rom[address + ((selected_rom_bank & 0x1F) - 1) * ROM_BANK_SIZE];
			else
				data = rom[address + (selected_rom_bank - 1) * ROM_BANK_SIZE];

			break;

		case 0xA:
		case 0xB:
			if(cart_ram && enable_cart_ram)
			{
				if(mbc == 3 && cart_ram_bank >= 0x08)
					data = rtc.cart_rtc[cart_ram_bank -
					0x08];
				else if((cart_mode_select || mbc != 1) &&
					cart_ram_bank < num_ram_banks)
				{
					data = ram[address - CART_RAM_ADDR +
						   (cart_ram_bank * CRAM_BANK_SIZE)];
				}
				else
					data = ram[address - CART_RAM_ADDR];
			}
			else
			{
				/* Cart RAM was not enabled. */
				data = 0xFF;
			}

			break;

		default:
			/* Ignore invalid addresses. */
			continue;
		}

		*tx_sm_do = data;

		in.data = data;
		multicore_fifo_push_blocking(in.raw);
	}
}

_Noreturn void core1_main(void){
	//save_and_disable_interrupts();
	core1_pio_manager();

	while(1)
		__wfi();
}

void __no_inline_not_in_flash_func(func_play)(const char *cmd)
{
	static bool started = false;
	unsigned long game_selection;
	union {
		struct __attribute__ ((__packed__)) {
			uint16_t address;
			uint8_t data;
			uint8_t is_write;
		};
		uint32_t raw;
	} in_stash[1024];
	unsigned in_i = 0;

	if(started == true)
	{
		printf("Core1 already started\n");
		multicore_reset_core1();
		pio_clear_instruction_memory(pio0);
		pio_sm_set_enabled(pio0, 0, false);
		pio_sm_set_enabled(pio0, 1, false);
	}

	cmd += strlen("PLAY ");
	game_selection = strtoul(cmd, NULL, 10);
	if(game_selection == 0)
	{
		printf("Select a game between 1 and 3:\nPLAY 1\n");
		return;
	}

	printf("Starting Core1\n");
	multicore_launch_core1(core1_main);
	multicore_fifo_push_blocking(game_selection);

	while(1)
	{
		uint32_t out;

		out = multicore_fifo_pop_blocking();
		switch(out)
		{
		case MULTICORE_CMD_SM_ENABLED:
			printf("State machines enabled\n");
			break;

		case MULTICORE_CMD_MBC_ACCEPTED:
			printf("MBC accepted\n");
			break;

		case MULTICORE_CMD_MBC_FAIL:
			printf("MBC check failed\n");
			goto err;

		case MULTICORE_CMD_ROM_ACCEPTED:
			printf("ROM accepted\n");
			break;

		case MULTICORE_CMD_ROM_FAIL:
			printf("ROM rejected\n");
			goto err;

		case MULTICORE_CMD_RAM_ACCEPTED:
			printf("RAM accepted\n");
			break;

		case MULTICORE_CMD_RAM_FAIL:
			printf("RAM rejected\n");
			goto err;

		case MULTICORE_CMD_PLAYING:
			printf("Playing\n");
			started = true;
			while(in_i < ARRAYSIZE(in_stash) &&
					getchar_timeout_us(0) != 'q')
			{
				bool popped;
				popped = multicore_fifo_pop_timeout_us(10,
					&in_stash[in_i].raw);
				if(popped == false)
					continue;

				in_i++;
			}
			for(unsigned i = 0; i < in_i; i++)
			{
				printf("%c %04X %02X\t",
					in_stash[i].is_write ? 'W' : 'R',
					in_stash[i].address,
					in_stash[i].data);
			}
			return;

		default:
			break;
		}
	}

err:
	printf("Core1 did not start properly\n");
	multicore_reset_core1();
	pio_clear_instruction_memory(pio0);

	return;
}

void func_set_clock(const char *cmd)
{
	unsigned long vco;
	cmd += strlen("PLAY ");
	vco = strtoul(cmd, NULL, 10);
	if(vco < 500 || vco > 1500)
	{
		printf("CLOCK VCO\n"
		       "CPU clock will be set to VCO/2\n"
		       "VCO must be between 1500 and 500\n");
		return;
	}

	vco *= 1000 * 1000;
	printf("Setting clock to %lu\n", vco / 2);
	sleep_ms(10);
	vreg_set_voltage(VREG_VOLTAGE_1_20);
	sleep_ms(10);
	set_sys_clock_pll(vco, 2, 1);
	sleep_ms(10);
}

inline uint8_t bcd_to_int(uint8_t x)
{
	return x - 6 * (x >> 4);
}

uint8_t decToBcd(uint8_t val)
{
	return ((val/10*16) + (val%10));
}

void func_rtcwrite(const char *cmd)
{
	int ret;
	datetime_t dt;
	uint8_t tx[8];

	tx[0] = RTC_SEC;

	//RTC WRITE <DOTW>:<DAY>/<MONTH>/<YEAR> <HOUR>:<MIN>:<SEC>
	ret = sscanf(cmd, "RTC WRITE %hhd:%hhd/%hhd/%hd %hhd:%hhd:%hhd",
		&dt.dotw, &dt.day, &dt.month, &dt.year,
		&dt.hour, &dt.min, &dt.sec);
	if(ret != 7)
	{
		printf("sscanf acquired only %d items of %d from string "
		       "'%s'\n", ret, 7, cmd);
		return;
	}

	if(rtc_set_datetime(&dt) == false)
	{
		printf("Failed to set internal RTC\n");
		return;
	}

	dt.year -= RTC_YEARS_EPOCH;
	tx[1] = dt.sec;
	tx[2] = dt.min;
	tx[3] = dt.hour;
	tx[4] = dt.dotw + 1;
	tx[5] = dt.day;
	tx[6] = dt.month;
	tx[7] = dt.year;

	for(unsigned i = 1; i < sizeof(tx); i++)
	{
		printf("%hd\t", tx[i]);
		tx[i] = decToBcd(tx[i]);
	}
	printf("\n");

	for(unsigned i = 1; i < sizeof(tx); i++)
	{
		printf("%#04x\t", tx[i]);
	}
	printf("\n");

	/* Set 24-hour bit of hour register. */
	tx[3] |= 0b01000000;

	ret = i2c_write_blocking(i2c_default, I2C_DS3231M_ADDR,
		tx, sizeof(tx), false);
	if(ret == PICO_ERROR_GENERIC)
	{
		printf("Error setting external RTC\n");
		return;
	}

	func_date(NULL);
	return;
}

void func_rtcread(const char *cmd)
{
	uint8_t tx = RTC_SEC;
	uint8_t rx[RTC_YEAR + 1];
	int ret;
	datetime_t dt;

	(void) cmd;

	/* Select second register. */
	ret = i2c_write_blocking(i2c_default, I2C_DS3231M_ADDR, &tx, 1, false);
	if(ret == PICO_ERROR_GENERIC)
	{
		printf("Error writing to RTC: %d\n", ret);
		return;
	}

	/* Read time values. */
	ret = i2c_read_blocking(i2c_default, I2C_DS3231M_ADDR, rx, sizeof(rx), false);
	if(ret == PICO_ERROR_GENERIC)
	{
		printf("Error reading from RTC: %d\n", ret);
		return;
	}

	dt.sec  = bcd_to_int(rx[RTC_SEC]);
	dt.min  = bcd_to_int(rx[RTC_MIN]);
	dt.hour = bcd_to_int(rx[RTC_HOUR] & 0b00111111);
	dt.dotw = rx[RTC_DAY] - 1;
	dt.day  = bcd_to_int(rx[RTC_DATE]);
	dt.month = bcd_to_int(rx[RTC_MONTH] & 0b00011111);
	dt.year = bcd_to_int(rx[RTC_YEAR]) + RTC_YEARS_EPOCH;
	/* TODO: Year 3000 problem? */

	rtc_init();
	if(rtc_set_datetime(&dt) == false)
	{
		printf("Datetime is not valid\n");
		for(unsigned i = 0; i < sizeof(rx); i++)
			printf("%02x ", rx[i]);

		printf("\n"
		       "%d %d %d %d %d %d %d\n",
			dt.sec, dt.min, dt.hour, dt.dotw, dt.day, dt.month,
			dt.year);
		return;
	}

	func_date(NULL);

	return;
}

void func_date(const char *cmd)
{
	char datetime_buf[256];
	char *datetime_str = &datetime_buf[0];
	datetime_t dt;

	(void) cmd;

	if(rtc_get_datetime(&dt) == false)
	{
		printf("RTC is not initialised\n");
		return;
	}
	datetime_to_str(datetime_str, sizeof(datetime_buf), &dt);
	printf("%s\n", datetime_str);
}

void func_rtctemp(const char *cmd)
{
	uint8_t tx = RTC_CONTROL_TEMP_MSB;
	uint8_t rx[2];
	const char *frac[4] = {
		".00", ".25", ".50", ".75"
	};
	int ret;
	int8_t t;

	(void) cmd;

	/* Select first temperature register. */
	ret = i2c_write_blocking(i2c_default, I2C_DS3231M_ADDR, &tx, 1, false);
	if(ret == PICO_ERROR_GENERIC)
	{
		printf("Error writing to RTC: %d\n", ret);
		return;
	}

	/* Read both temperature registers. */
	ret = i2c_read_blocking(i2c_default, I2C_DS3231M_ADDR, rx, sizeof(rx), false);
	if(ret == PICO_ERROR_GENERIC)
	{
		printf("Error reading from RTC: %d\n", ret);
		return;
	}

	t = (int8_t)rx[0];

	rx[1] >>= 6;
	printf("Temperature: %d%s Celsius\n", t, frac[rx[1]]);

	return;
}

// I2C reserves some addresses for special purposes. We exclude these from the scan.
// These are any addresses of the form 000 0xxx or 111 1xxx
bool reserved_addr(uint8_t addr)
{
	return (addr & 0x78) == 0 || (addr & 0x78) == 0x78;
}

void func_i2cscan(const char *cmd)
{
	(void) cmd;

	printf("\nI2C Bus Scan\n");
	printf("   0  1  2  3  4  5  6  7  8  9  A  B  C  D  E  F\n");

	for (int addr = 0; addr < (1 << 7); ++addr)
	{
		int ret;
		uint8_t rxdata;

		if (addr % 16 == 0)
		{
			printf("%02x ", addr);
		}

		// Perform a 1-byte dummy read from the probe address. If a slave
		// acknowledges this address, the function returns the number of bytes
		// transferred. If the address byte is ignored, the function returns
		// -1.

		// Skip over any reserved addresses.
		if (reserved_addr(addr))
			ret = PICO_ERROR_GENERIC;
		else
			ret = i2c_read_blocking(i2c_default, addr, &rxdata, 1, false);

		printf(ret < 0 ? "_" : "@");
		printf(addr % 16 == 15 ? "\n" : "  ");
	}
}

void func_i2csend(const char *cmd)
{
	int ret;
	uint8_t addr;
	uint8_t data[8];
	unsigned len = 0;
	char *endptr;

	(void) cmd;

	if(strlen(cmd) < strlen("I2C SEND 0x00 0x00"))
	{
		printf("Syntax error: string length incorrect\n");
		return;
	}

	cmd += strlen("I2C SEND");
	addr = (uint8_t)strtol(cmd, &endptr, 0);
	if(endptr == cmd && addr == 0)
	{
		printf("Syntax error: failed to decode address\n");
		return;
	}

	cmd = endptr;
	data[len] = (uint8_t)strtol(cmd, &endptr, 0);
	if(endptr == cmd && data[0] == 0)
	{
		printf("Syntax error: failed to decode data\n");
		return;
	}
	len++;

	while(len < sizeof(data))
	{
		cmd = endptr;
		data[len] = (uint8_t)strtol(cmd, &endptr, 0);
		if(endptr == cmd && data[len] == 0)
			break;

		len++;
	}

	printf("Sending command %#04x with %d bytes to %#04x\n", data[0], len,
		addr);

	ret = i2c_write_blocking(i2c_default, addr, data, len, false);
	if(ret == PICO_ERROR_GENERIC)
		printf("Error %d\n", ret);
	else
		printf("Sent %d byte(s)\n", ret);
}

void func_i2crecv(const char *cmd)
{
	int ret;
	uint8_t addr;
	char *endptr;
	uint8_t dat[1];

	(void) cmd;

	if(strlen(cmd) != strlen("I2C RECV 0x00"))
	{
		printf("Syntax error: string length incorrect\n");
		return;
	}

	cmd += strlen("I2C RECV");
	addr = (uint8_t)strtol(cmd, &endptr, 0);
	if(endptr == cmd && addr == 0)
	{
		printf("Syntax error: failed to decode address\n");
		return;
	}

	printf("Receiving byte from %#04x\n", addr);

	ret = i2c_read_blocking(i2c_default, addr, dat, sizeof(dat), false);
	if(ret == PICO_ERROR_GENERIC)
		printf("Error %d\n", ret);
	else
	{
		printf("Received byte: %#04x, 0b", dat[0]);
		for(int i = 7; i >= 0; i--)
			printf("%d", (dat[0] >> i) & 1);

		printf("\n");
	}
}

void func_gb(const char *cmd)
{
	bool turn_gb_on;

	cmd += strlen("GB ");
	if(*cmd == '1')
		turn_gb_on = true;
	else if(*cmd == '0')
		turn_gb_on = false;
	else
	{
		printf("Syntax error\n");
		return;
	}

	power_gb(turn_gb_on);
	return;
}

void func_reboot(const char *cmd)
{
	(void) cmd;
	reset_usb_boot(0, 0);
}
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
int main(void)
{
	/* Reduce power consumption to stop IO Expander Power-On Reset Errata. */
	sleep_ms(10);

	/* Set system clock to 276MHz and flash to 138MHz. */
	{
		const unsigned vco = 552000000;
		const unsigned div1 = 2, div2 = 1;

		vreg_set_voltage(VREG_VOLTAGE_1_15);
		sleep_ms(10);
		set_sys_clock_pll(vco, div1, div2);
		sleep_ms(10);
	}

	i2c_init(i2c_default, 100 * 1000);
	gpio_set_function(PICO_DEFAULT_I2C_SDA_PIN, GPIO_FUNC_I2C);
	gpio_set_function(PICO_DEFAULT_I2C_SCL_PIN, GPIO_FUNC_I2C);
	gpio_disable_pulls(PICO_DEFAULT_I2C_SDA_PIN);
	gpio_disable_pulls(PICO_DEFAULT_I2C_SCL_PIN);

	// Make the I2C pins available to picotool
	bi_decl_if_func_used(bi_2pins_with_func(PICO_DEFAULT_I2C_SDA_PIN,
		PICO_DEFAULT_I2C_SCL_PIN, GPIO_FUNC_I2C));

	for(unsigned i = PIO_PHI; i <= PIO_A15; i++)
	{
		gpio_set_input_enabled(i, true);
		/* Disable schmitt triggers on GB Bus. The bus transceivers
		 * already have schmitt triggers. */
		gpio_set_input_hysteresis_enabled(i, false);
	}

#if 1
	for(unsigned i = PIO_PHI; i <= PIO_DIR; i++)
	{
		/* Use fast slew rate for GB Bus. */
		gpio_set_slew_rate(i, GPIO_SLEW_RATE_FAST);
	}
#endif

	/* Set external RTC configuration. */
	{
		uint8_t tx[2];
		tx[0] = RTC_CONTROL;
		tx[1] = 0b00111100;
		i2c_write_blocking(i2c_default, I2C_DS3231M_ADDR, tx,
			sizeof(tx), false);
	}

	/* Set external IO expander configuration. */
	{
		uint8_t tx[2];
		tx[0] = IO_EXP_DIRECTION;
		tx[1] = 0b11111110;
		i2c_write_blocking(i2c_default, I2C_PCA9536_ADDR, tx,
				   sizeof(tx), false);
	}

	//gpio_set_drive_strength(PIO_DIR, GPIO_DRIVE_STRENGTH_12MA);
	//gpio_set_function(PIO_DIR, GPIO_FUNC_PIO0);
	//gpio_set_dir(PIO_DIR, true);
	//gpio_put(PIO_DIR, 1);

	func_gb("GB 1");
	bi_decl_if_func_used(bi_program_feature("PIO0 Game Boy Bus"));

	/* If baudrate is set to PICO_STDIO_USB_RESET_MAGIC_BAUD_RATE, then the
	 * RP2040 will reset to BOOTSEL mode. */
	stdio_init_all();

	//func_play("PLAY 3");
	printf("%s", CLR_SCRN);
	usb_commander();

	return 0;
}

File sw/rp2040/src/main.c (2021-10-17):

#include <sys/cdefs.h>
#include <hardware/pio.h>
#include <hardware/i2c.h>
#include <hardware/rtc.h>
#include <hardware/sync.h>
#include <hardware/irq.h>
#include <pico/binary_info.h>
#include <pico/bootrom.h>
#include <pico/multicore.h>
#include <pico/unique_id.h>
#include <tusb.h>

#include <main.h>
#include <peripherals/io_expander.h>
#include <peripherals/rtc.h>
#include <pico/stdlib.h>
#include <hardware/vreg.h>

#include "comms.pio.h"

static inline void multicore_fifo_push_inline(uint32_t data)
{
	if(multicore_fifo_wready() == false)
		return;

	sio_hw->fifo_wr = data;
	__sev();
}

_Noreturn void core1_entry(void)
{
#if 1
	tusb_init();

	{
		uint8_t buffer[5+PICO_UNIQUE_BOARD_ID_SIZE_BYTES];
		buffer[0] = 'R';
		buffer[1] = rp2040_rom_version();
		buffer[2] = 'C';
		buffer[3] = rp2040_chip_version();
		buffer[4] = 'U';
		pico_get_unique_board_id((pico_unique_board_id_t *) &buffer[5]);
		tud_hid_report(0, buffer, sizeof(buffer));
		tud_task();
	}

	while (1)
	{
		uint32_t buffer[8];
		unsigned len = 0;

		buffer[len++] = multicore_fifo_pop_blocking();
		while(multicore_fifo_rvalid())
		{
			buffer[len++] = sio_hw->fifo_rd;
			if(len == 8)
				break;
		}

		if(tud_hid_ready())
		{
			uint8_t sz = len * sizeof(uint32_t);
			tud_hid_report(0, buffer, sz);
		}

		tud_task();
	}

#else
	while(1)
		__wfi();
#endif
}

void pio0_irq0(void)
{
#include "gb_manager.gb.h"
	static uint_fast16_t address = 0;

	irq_clear(PIO0_IRQ_0);

	if(pio_sm_is_rx_fifo_empty(pio0, PIO_SM_A15) == false)
	{
		uint32_t val = pio_sm_get(pio0, PIO_SM_A15);
		/**
		 * PIO_SM_A15 state machine RX value:
		 * | 8-bit Data | 16-bit Address | CS | RD | PHI | 00000 |
		 * | Unused     | Readable       | U  | R  | U   | UUUUU |
		 * Legend: U-Unused, R-Readable
		 */
		bool rd;

		multicore_fifo_push_inline(val);
		address = (val & 0x00FFFF00) >> 8;
		rd = (val & 0b01000000) != 0;

		/* If RD is HIGH, then the Game Boy wants to write data to the
		 * given address, however, the data is not ready when this read
		 * takes place. The address is saved in the static variable to
		 * allow the PIO_SM_DI to write to that address. */
		if(rd == true)
			return;

		/* TODO: CS and PHI are not useful. */

		/* Check that address is within range. */
		/* TODO: Maybe change this to assert? */
		if(address >= gb_manager_rom_len)
			address = 0;

		pio_sm_put(pio0, PIO_SM_DO, gb_manager_rom[address]);
	}
	else if(pio_sm_is_rx_fifo_empty(pio0, PIO_SM_CS) == false)
	{
		uint32_t val = pio_sm_get(pio0, PIO_SM_CS);
		bool rd;

		multicore_fifo_push_inline(val);
		address = (val & 0x00FFFF00) >> 8;
		rd = (val & 0b01000000) != 0;
		if(rd == true)
			return;

		/* Do not perform any action on internal addresses. */
		if(address >= 0xC000)
			return;

		/* TODO: Implement RAM read. */
		pio_sm_put(pio0, PIO_SM_DO, 0x00);
	}
	else if(pio_sm_is_rx_fifo_empty(pio0, PIO_SM_DI) == false)
	{
		uint32_t val = pio_sm_get(pio0, PIO_SM_DI);
		//uint8_t data = val >> 24;

		/* This state machine requires the previously acquired address
		 * value. */

		multicore_fifo_push_inline(val);
		/* TODO: Implement banking. */
		/* TODO: Implement RAM writing. */
	}

	return;
}

void start_io_expander(void)
{
	/* Check that the IO expander is connected. */
	if(i2c_io_exp_init(i2c0) != PICO_OK)
	{
		/* Connection to the IO expander is mandatory. If that fails,
		 * then reboot to USB for reprogramming, debugging, etc. */
		reset_usb_boot(0, 0);
		__builtin_unreachable();
	}

	/* Set pin directions on the IO expander. */
	i2c_io_exp_set_reg(i2c0, IO_EXP_DIRECTION);
	i2c_io_exp_write_reg(i2c0, (IO_EXP_DIR_UNUSED << IO_EXP_UNUSED_PIN) |
		(IO_EXP_DIR_OUTPUT << IO_EXP_STATLED_PIN) |
		(IO_EXP_DIR_INPUT << IO_EXP_SWITCH_PIN) |
		(IO_EXP_DIR_OUTPUT << IO_EXP_GB_RESET_PIN));

	/* Hold Game Boy in reset before checking for button press.
	 * Initialise LED to be off. */
	i2c_io_exp_set_reg(i2c0, IO_EXP_OUTPUT_PORT);
	i2c_io_exp_write_reg(i2c0,
		(0 << IO_EXP_STATLED_PIN) | (1 << IO_EXP_GB_RESET_PIN));

	{
		uint8_t in;

		/* Check to see if button is pressed. */
		i2c_io_exp_set_reg(i2c0, IO_EXP_INPUT_PORT);
		i2c_io_exp_read_reg(i2c0, &in);
		/* If button isn't being pressed down, do nothing. */
		if(in & (1 << IO_EXP_SWITCH_PIN))
			return;

		/* If button is being held down, reboot to USB Boot mode. */
		/* Turn on the LED to show that we're in USB Boot mode due to
		 * user pushing button. */
		i2c_io_exp_set_reg(i2c0, IO_EXP_OUTPUT_PORT);
		i2c_io_exp_write_reg(i2c0, (1 << IO_EXP_STATLED_PIN));

		reset_usb_boot(0, 0);
		__builtin_unreachable();
	}
}

void start_rtc(void)
{
	datetime_t dt;

	/* Initilise internal RTC. */
	rtc_init();

	/* Initiliase external I2C RTC. */
	if(i2c_rtc_init(i2c0) != PICO_OK)
		return;

	/* Read date and time from external RTC. */
	if(i2c_rtc_read_time(i2c0, &dt) != PICO_OK)
		return;

	/* Set date and time to internal RTC. */
	if(rtc_set_datetime(&dt) != PICO_OK)
		return;
}
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

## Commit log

2021-08-24 Finish schematic
    [gb_rp2040_cart.kicad_pcb, gb_rp2040_cart.kicad_sch]
2021-08-24 Refactor external footprints & libraries
2021-08-24 Add full DMG cart footprint
    [gb_rp2040_cart.kicad_pcb]
2021-08-24 Use RP2040 instead of Pico
    [gb_rp2040_cart.kicad_sch]
2021-08-25 hw: connect cart to RP2040
    [gb_pico_cart.kicad_pcb, gb_rp2040_cart.kicad_sch]
2021-08-26 hw: start PCB layout
    [gb_rp2040_cart.kicad_pcb, gb_rp2040_cart.kicad_sch]
2021-08-28 hw: finish layout
    [CLXC8T245QRHLRQ1.stp, USB4105-GF-A.step, gb_rp2040_cart.kicad_pcb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]
2021-08-30 Finish routing & final checks
    [gb_rp2040_cart.kicad_pcb, gb_rp2040_cart.kicad_sch]
2021-08-31 Simplify circuit
    [gb_rp2040_cart.kicad_pcb, gb_rp2040_cart.kicad_sch]
2021-09-01 Layout components of simplified circuit
    [RP2040.kicad_sch, USB.kicad_sch, gb_rp2040_cart.kicad_pcb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]
2021-09-02 Complete layout and start placing tracks
    [RP2040.kicad_sch, gb_rp2040_cart.kicad_pcb, gb_rp2040_cart.kicad_sch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]
2021-09-09 rp2040: add PIO to CMakeLists & fix syntax errors
    [main.c]
2021-09-09 hw: use parts from LCSC
    [RP2040.kicad_sch, USB.kicad_sch, gb_pico_cart.kicad_pcb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]
2021-09-11 hw: complete 2-layer PCB
    [RP2040.kicad_sch, USB.kicad_sch, gb_rp2040_cart.kicad_pcb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]
2021-09-11 hw: replace RTC
    [gb_rp2040_cart.kicad_pcb, gb_rp2040_cart.kicad_sch, peripherals.kicad_sch]
2021-09-13 hw: complete routing
    Use components available on LCSC.
    [RP2040.kicad_sch, gb_rp2040_cart.kicad_pcb, gb_rp2040_cart.kicad_sch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]
2021-09-13 hw: add more information to BOM
    [RP2040.kicad_sch, USB.kicad_sch, gb_rp2040_cart.kicad_sch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]
2021-09-28 hw: fix USB
    Additionally reduced the size of the battery holder.
    [RP2040.kicad_sch, USB.kicad_sch, gb_rp2040_cart.kicad_pcb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]
2021-09-29 hw: add BOOTSEL button and routing changes
    [RP2040.kicad_sch, USB.kicad_sch, gb_rp2040_cart.kicad_pcb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]
2021-09-29 sw: verify: add I2C commands
2021-09-30 hw: use CR2032 footprint & larger testpoints
    [RP2040.kicad_sch, gb_rp2040_cart.kicad_pcb, gb_rp2040_cart.kicad_sch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]
2021-09-30 sw: add RTC date and temperature commands
2021-10-01 sw: verify: fix PIO read & add BUS viewer
    [verify.c]
2021-10-02 sw: verify: displays logo correctly
    [verify.c]
2021-10-03 sw: verify: fix data direction logic
    [verify.c]
2021-10-05 sw: basic: further simplify
    [configuration.h]
2021-10-06 sw: perform clock speed tests
    [configuration.h]
2021-10-06 hw: use nets for decoupling capacitors
    [RP2040.kicad_sch, gb_rp2040_cart.kicad_sch, power.kicad_sch]
2021-10-07 Revert "sw: verify: write to specific byte in PIO FIFO"
    This reverts commit 3958661f8cf03c718db780ac8a97372e60276e9e.
    [verify.c]
2021-10-08 More attempts
    [RP2040.kicad_sch, gb_rp2040_cart.kicad_pcb, gb_rp2040_cart.kicad_sch]
2021-10-14 sw: verify: working MBC1
    Fixed an issue whereby flash reads were taking longer than required.
    [verify.c]
2021-10-14 sw: remove boot_stage2 test
    [configuration.h]
2021-10-14 hw: minor rearranging of symbols
    [NEW_PCB_2021-09-30.pcbdoc, OBJ_NEW_PCB.obj, RP2040.kicad_sch]
2021-10-17 sw: add MBC3 and bus traceback
2021-10-19 sw: WIP to improve flash read speed
    [configuration.h]
2021-10-20 sw: basic: remove USB support
    Instead, use double reset to USBBOOT.
    Also, strip libbet.gb to use less space.
    [impl.c]
2021-10-20 sw: basic: fix GB power setting
    [impl.c]
2021-10-21 sw: fix rom listing
    [rp2040.c]
2021-10-22 sw: change cart API address to logo
    This stops the use of the interrupt locations in ROM.
2021-10-22 sw: remove MBC2 support & fix unused RAM size
    [rp2040.c]
2021-10-24 hw: multiplex Game Boy bus pins
    [RP2040.kicad_sch, USB.kicad_sch, gb_rp2040_cart.kicad_sch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]
2021-10-25 hw: begin layout
    [RP2040.kicad_sch, gb_rp2040_cart.kicad_pcb, gb_rp2040_cart.kicad_sch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]
2021-10-28 sw: fix ROM banking
    [rp2040.c]
2021-10-28 hw: WIP
    [RP2040.kicad_sch, USB.kicad_sch, gb_rp2040_cart.kicad_pcb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]
2021-10-30 all: Add open source license
    [RP2040.kicad_sch, USB.kicad_sch, gb_rp2040_cart.kicad_sch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]
2021-10-31 sw: fix saving to FRAM
    Saving to FRAM is done by pressing the button.
    [rp2040.c]
2021-11-01 sw: fix mgmt code block not removed
    [rp2040.c]
2021-11-01 sw: push button on power-on to USBBOOT
2021-11-11 sw: force i2c function into RAM
2021-11-11 sw: increase core clock slightly
    I had one crash after two hours of gameplay, which could be due to a
    missed clock cycle.
    [rp2040.c]
2021-11-11 sw: use RAM function for I2C writes
2021-11-13 Revert "sw: use RAM function for I2C writes"
    This reverts commit a6971874b09dea2a477451fc3da306e201b12757.
    [rp2040.c]
2021-11-13 Revert "sw: force i2c function into RAM"
    This reverts commit 4ecf91308a94141c7efec92500e1069299468e2b.
    [rp2040.c]
2021-11-14 hw: remove DIP switch and LED
    [RP2040.kicad_sch, gb_rp2040_cart.kicad_pcb, gb_rp2040_cart.kicad_sch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]
2021-11-14 sw: add RTC & use low power sleep
2021-11-16 hw: route multiplexed gb bus circuit
    The lower address, higher address and data bits are multiplexed together
    to a single 8-bit bus on the RP2040. This allows the FRAM to be
    connected via SPI for faster communication speed, and allows for a
    cheaper RTC component to be used. Furthermore, a vibration motor has
    been added.
    [RP2040.kicad_sch, bom.csv, gb_rp2040_cart.kicad_pcb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]
2021-11-18 sw: dmg: use interrupts for vblank delay
2021-11-24 sw: dmg: print hello world in custom font
    Font is public domain by Reddit user graspee.
2021-12-02 sw: significant work for v0.4
    Started work on DS1302 PIO communication.
    LED is tested working.
2021-12-03 sw: verify: reduce power consumption
    [peripherals.kicad_sch]
2021-12-18 sw: fix GB comms with new PIO program
    [rp2040.c, verify.c]
2021-12-24 sw: use interrupts for A15 handling
2021-12-26 sw: booting MBC1 test ROM (fails though)
    [rp2040.c, rp2040_old.c, verify.c]
2021-12-26 sw: fix MBC[1,3] ROM reads
    [rp2040.c]
2021-12-27 sw: fix saving to FRAM
    [rp2040.c, verify.c]
2021-12-27 sw: only save to FRAM on cart write
    Additionally made the LED act as a FRAM writing indicator.

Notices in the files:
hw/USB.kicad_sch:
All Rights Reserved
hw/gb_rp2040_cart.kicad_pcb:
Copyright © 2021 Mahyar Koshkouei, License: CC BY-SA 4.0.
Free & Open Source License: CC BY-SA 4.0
